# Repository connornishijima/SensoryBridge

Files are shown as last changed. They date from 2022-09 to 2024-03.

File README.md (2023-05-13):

https://github.com/connornishijima/SensoryBridge/assets/5051485/211737f4-0c69-49b0-99c4-2fa3d6a7a65e

# SENSORY BRIDGE is **DIFFERENT**

**This isn't the usual "sound-reactive LEDs" you've seen for years.**

**Sensory Bridge is built from the ground up as an open, powerful bridge between sight and sound.** With a show that's reactive to notation, vibrato and more, it produces very unique and pleasant-to-look-at light shows which synchronize to your music without any visible latency. (A built-in MEMS microphone constantly studies what it hears using a special-sauce Goertzel-based Discrete Fourier Transform, at 100 FPS!)

It has to be seen to be believed, *which the video demos below can help with:*

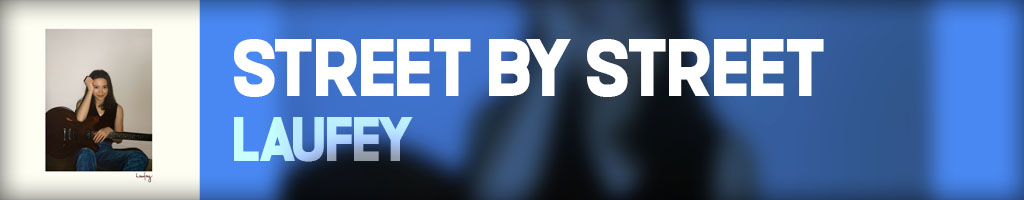
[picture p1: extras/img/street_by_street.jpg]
STREET BY STREET (https://www.youtube.com/watch?v=trJYa3U8nCU)

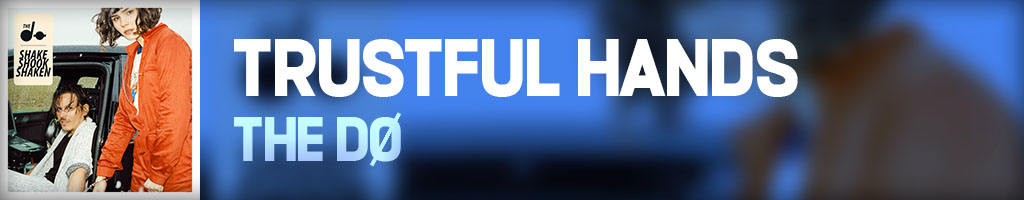
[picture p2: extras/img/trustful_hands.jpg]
TRUSTFUL_HANDS (https://www.youtube.com/watch?v=0EICjxSjveM)

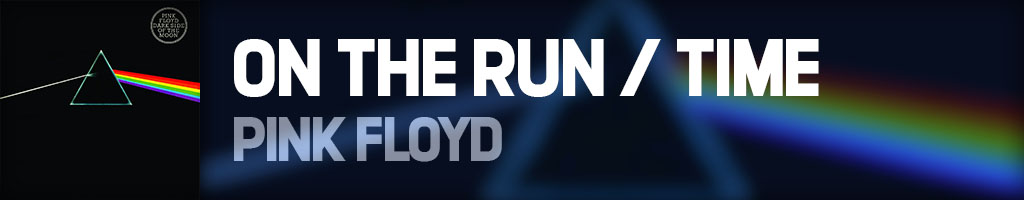
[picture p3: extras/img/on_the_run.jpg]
ON THE RUN (https://www.youtube.com/watch?v=RWJjWcHplGc)

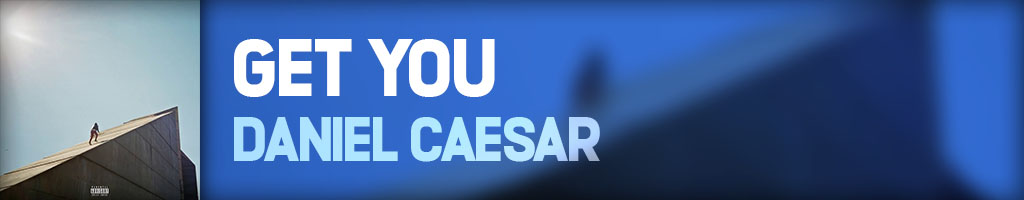
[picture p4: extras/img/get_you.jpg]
GET YOU (https://www.youtube.com/watch?v=lk1oRJr7TGo)

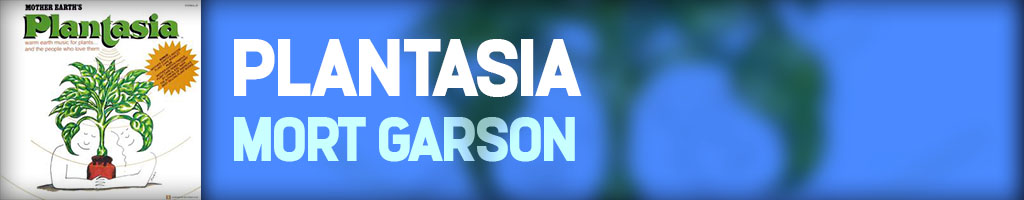
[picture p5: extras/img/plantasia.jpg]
PLANTASIA (https://www.youtube.com/watch?v=Hz8LxBKy5SI)

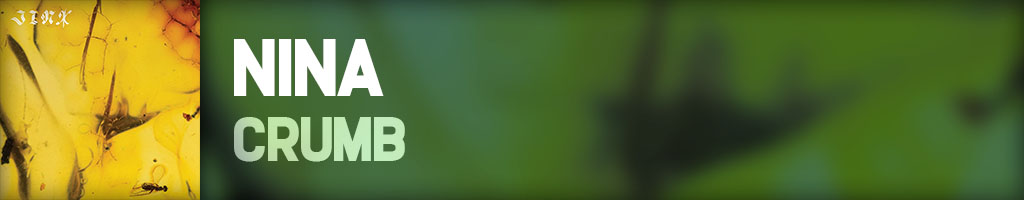
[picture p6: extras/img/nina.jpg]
NINA (https://www.youtube.com/watch?v=OXu3x7s3SVE)


# 

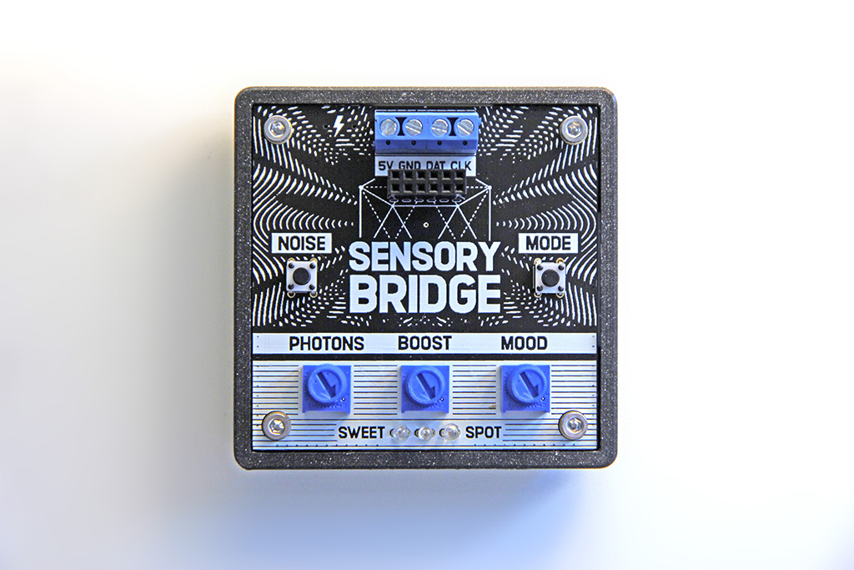
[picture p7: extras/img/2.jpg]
SENSORY BRIDGE IS SIMPLE


# SENSORY BRIDGE is **SIMPLE**

**Easy controls provide quick access to changing the brightness, color, and smoothing of the display!**

# **KNOBS**

## PHOTONS KNOB

Too bright? *Dim down the show* with the **PHOTONS** knob. The FastLED code in the firmware will use dithering to keep producing color nicely at lower brightness levels.

## CHROMA KNOB

Custom color or automated color based on the music's notation? Choose with the **CHROMA** knob, where turning it all the way to the top enables automated color changes.

## MOOD KNOB

This knob is special. **MOOD** controls *how quickly your LEDs will react to changes in pitch and volume!* A low "mood" will be very soft and gradual, only showing things like the underlying chord progression of a song, whereas a *high* "mood" will be extremely reactive, and can be a little too flashy for some people's liking. Luckily, you can blend the value to anywhere between those two extremes whenever you want to find what look you prefer!

# 

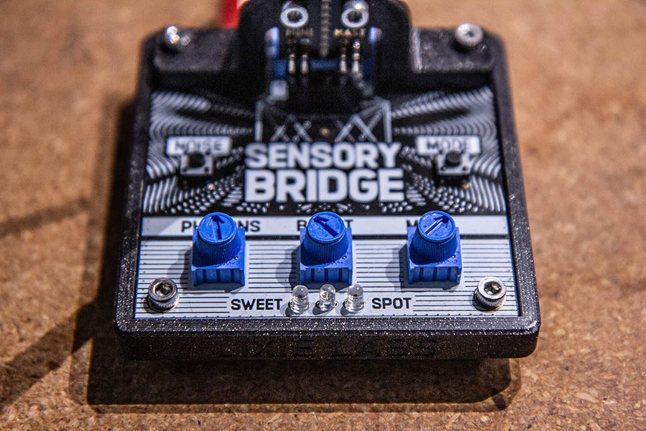
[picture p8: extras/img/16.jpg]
KNOBS


# **BUTTONS**

## NOISE BUTTON

Running the A/C? Is the washing machine suddenly on the spin cycle? Don't worry, just pause the music for a moment and press the **NOISE BUTTON** to run a 3-second calibration to *automagically* have noisy background ambience removed from your light show.

## MODE BUTTON

Sensory Bridge currently has 6 built-in light show modes that you can cycle through:

### "Spectrogram Mode"

This is the default show seen in the videos, based on Discrete Fourier Transform data. Each octave of notation shown on the display has a spectrum of colors for the individual notes, which are lit in sync with your music!

### "Chromagram Mode"

Similar to Spectrogram Mode, but all octaves of notes are rolled into one! Best with the **MOOD** knob at a low to medium setting.

### "Bloom Mode"

This mode differs from the others. The intensity of the audio is shown in the center of the LED strip, and is diffused outward in a non-linear fashion as time passes, leading to a 2001 "Stargate Sequence" effect!. Color is derived from the notes your music is playing.

### "Bloom Mode" (Faster)

Same as above, but double the speed for when you're partying hard!

### "VU Meter Mode"

It's a classic! A bouncing bar graph represents the current loudness of the music.

### "VU Meter Mode (Dot)"

Same as above, but represented with a dot instead of a bar, staying a constant brightness.

## ***MORE MODES WILL BE RELEASED IN FUTURE FIRMWARE UPDATES!***

# 

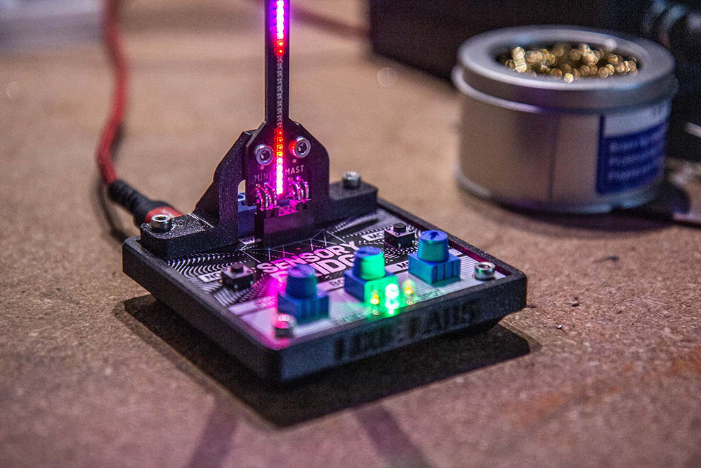
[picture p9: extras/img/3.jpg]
SWEET SPOT


# **SWEET SPOT**

At the front of the base unit are three LEDs, which indicate if your music is playing too quietly for the auto-ranger to account for, or if it's too loud! (Close to clipping!)

# 

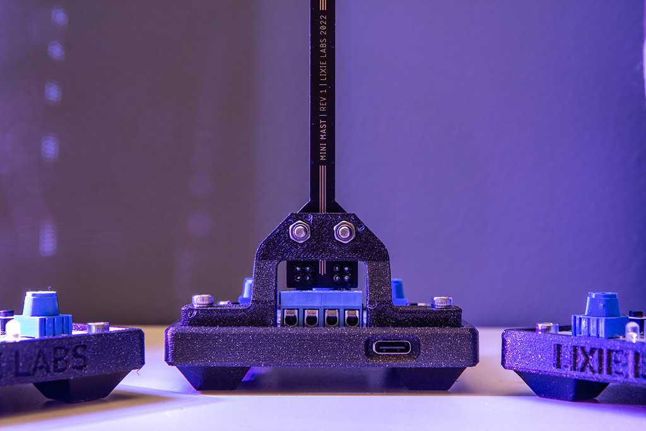
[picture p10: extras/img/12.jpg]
SENSORY BRIDGE IS FLEXIBLE


# SENSORY BRIDGE is **FLEXIBLE**

While compatible with any WS2812B or APA102/SK9822-based LED strip (just use the screw terminals at the back!) there's also the option of using the **"Mini Mast"**, a dense strip of 128 1.5mm RGB LEDs on a 260mm long PCB! It just plugs directly into the Sensory Bridge accessory port, making for a very portable solution!

# 

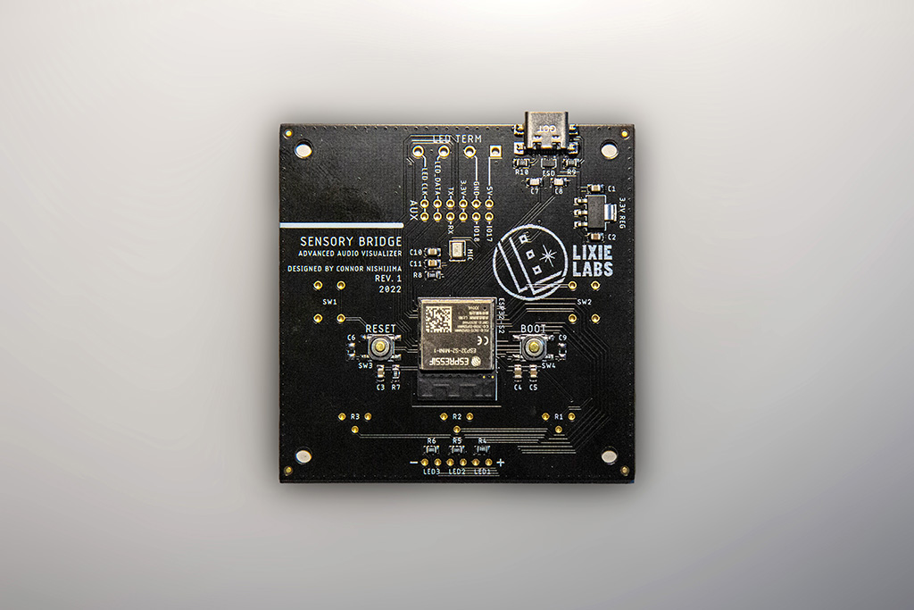
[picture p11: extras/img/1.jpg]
SENSORY BRIDGE IS OPEN


# SENSORY BRIDGE is **OPEN**

--------------------------------------------------------

### NOTE: This repo is used for active development.

For the latest stable release of the Sensory Bridge firmware, **[visit the Releases page](https://github.com/connornishijima/SensoryBridge/releases)**! (Cloning straight from this repo is much like a "nightly" build, and may be broken code!)

--------------------------------------------------------

Powered by an ESP32-S2, Sensory Bridge can be easily reprogrammed for any purpose you'd like! The firmware is [open source](https://github.com/connornishijima/SensoryBridge) under the [MIT License](https://github.com/connornishijima/SensoryBridge/blob/main/LICENSE), so modifying it for your own purposes is quick and easy with the Arduino IDE. You can even download the [board](https://github.com/connornishijima/SensoryBridge/tree/main/extras/OSHW/PCB) and [case STLs](https://github.com/connornishijima/SensoryBridge/tree/main/extras/OSHW/3D%20Printing) to build one yourself!

OSHW FACTS

# 

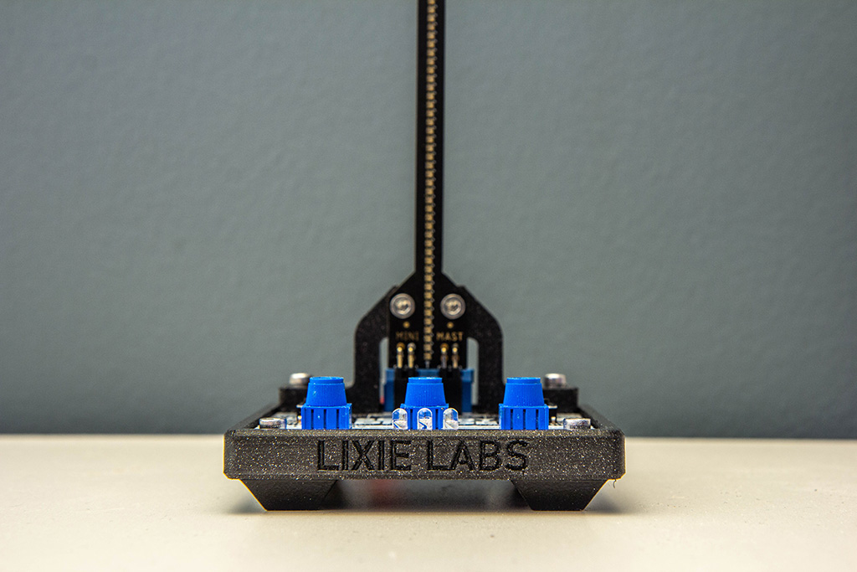
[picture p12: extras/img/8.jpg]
WHATS INCLUDED


# WHAT'S **INCLUDED:**

For $50, you'll receive a ***fully assembled Sensory Bridge***, with the latest firmware already installed. For $25 extra, you can have a **Mini Mast** (128 micro-LED PCB, seen above) sent as well, with an accompanying brace that provides rigidity. (It just plugs right into the accessory port on top of Sensory Bridge!)

# EXTRAS YOU **MIGHT NEED:**

## **PAY CLOSE ATTENTION TO THIS SECTION!**

To save on redundant materials you might already own, **your Sensory Bridge does *not* come with the following items:**

- **WS2812B LED Strip** - "144-LEDs per meter" variants are recommended, you can cut the 16 excess LEDs off of the end of the strip or reconfigure your device to interpolate to the 144-LED length at a slightly lower frame rate. ([AMAZON LINK](https://www.amazon.com/WS2812B-Individual-Addressable-144Pixels-Non-Waterproof/dp/B09PBHJG6G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))
- **USB-C Cable** ([AMAZON LINK](https://www.amazon.com/JSAUX-Charger-Braided-Compatible-Samsung/dp/B076FPGWNZ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))
- **5V, 2A USB Power Adapter** ([AMAZON LINK](https://www.amazon.com/Certified-Charger-FONKEN-Universal-Compatible/dp/B07DF782WQ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))
- **Wire Stripper** - If you'd like to use your Sensory Bridge with your own LED strip, you'll either need a wire stripper or strong teeth to get it hooked up neatly! These clamp-style strippers make that process a breeze, so please don't use your teeth: ([AMAZON LINK](https://www.amazon.com/Self-Adjusting-Stripper-Klein-Tools-11061/dp/B00CXKOEQ6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))

# 

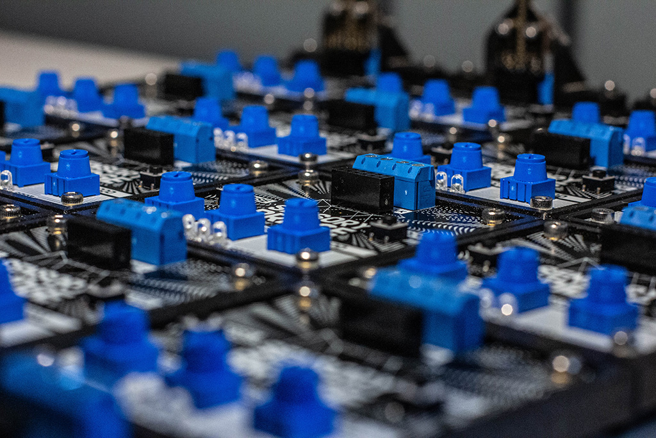
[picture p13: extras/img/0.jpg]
FUTURE PLANS


# FUTURE **PLANS**

Sensory Bridge is going to undergo some upgrades in the following months! You'll be able to easily [update to the latest firmware in minutes with this guide](DEAD LINK).

**Currently planned features are:**

## WiFi Features

Planned for Q1 2023 is a mobile / web app for iOS and Android that will allow users to remotely tweak their display from the couch! This will provide a way to adjust dozens of settings that otherwise couldn't be accessed through just two physical buttons.

## More Lightshow Modes

Currently in development is a system of determining and synchronizing to the BPM of the playing music. Combining this data with the GDFT could mean deducing time signatures, along with musical keys and chord progressions - just another avenue for providing an immersive show!

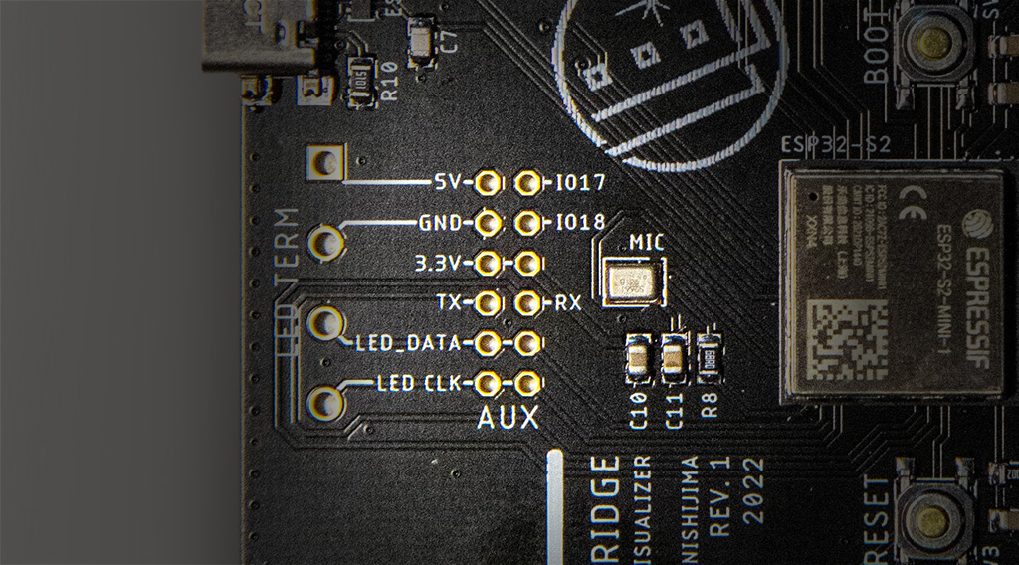
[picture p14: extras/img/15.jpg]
AUX PORT


## Support For Line-In Audio

The accessory port exposes GPIO 17/18 of the ESP32-S2, which are analog inputs. In the future, a PCB can be made to allow Sensory Bridge to use hardwired, passthrough audio via two 3.5mm jacks. This concept does not interfere with the Mini Mast, and the two accessories will be stackable with a modified brace.

GETTING STARTED GUIDE

# **GETTING STARTED**

The **[GETTING STARTED](https://sensorybridge.rocks/tutorial/) GUIDE** will walk you through the quick-and-easy setup process!

# **DISCLAIMER**

## **Those with [Photosensitive Epilepsy](https://en.wikipedia.org/wiki/Photosensitive_epilepsy) (PSE) should NOT purchase, operate, or otherwise view Sensory Bridge under any condition.**

## **The seller assumes no legal liability for injury caused to persons with PSE that have ignored this warning.**

# **SPONSORS**

- **[mlctrez](https://github.com/mlctrez)**
- **[zxcasd](https://github.com/zxcasd-zxcasd)**

# **CREDITS**

Developed by Connor Nishijima for Lixie Labs (2022)

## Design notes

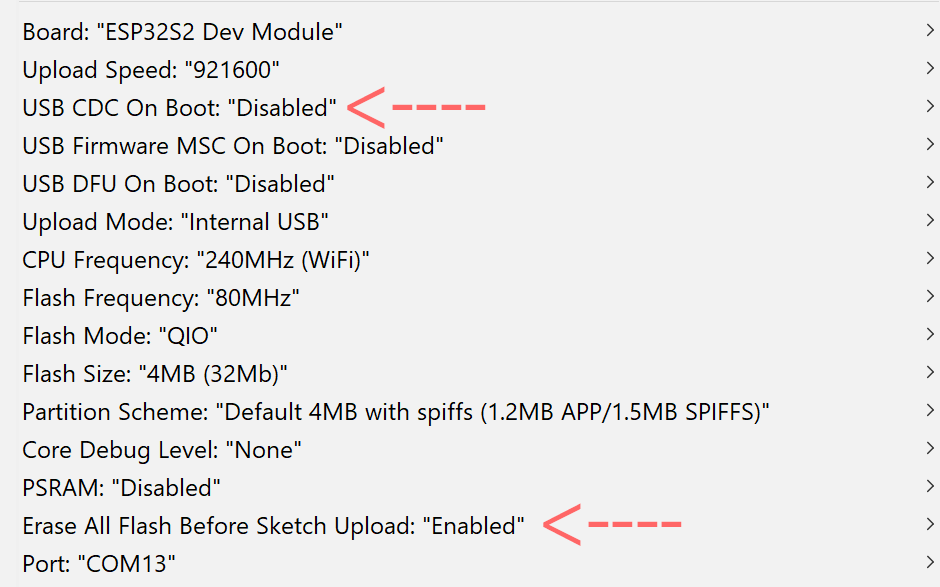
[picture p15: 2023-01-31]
extras/img/firmware_settings_300.png

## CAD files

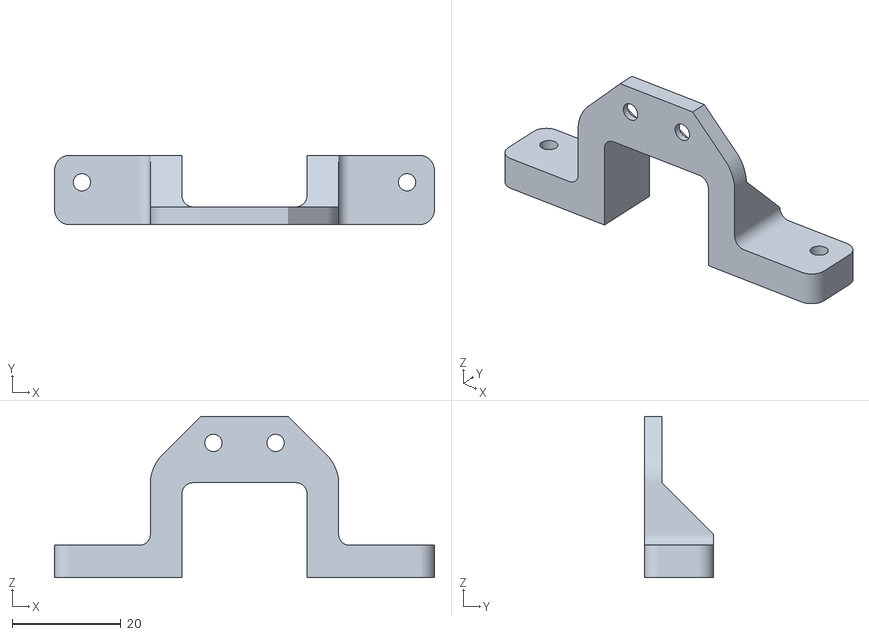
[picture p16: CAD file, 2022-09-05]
extras/OSHW/3D Printing/MINI_MAST_MOUNT.stl
70.0 x 12.8 x 29.7

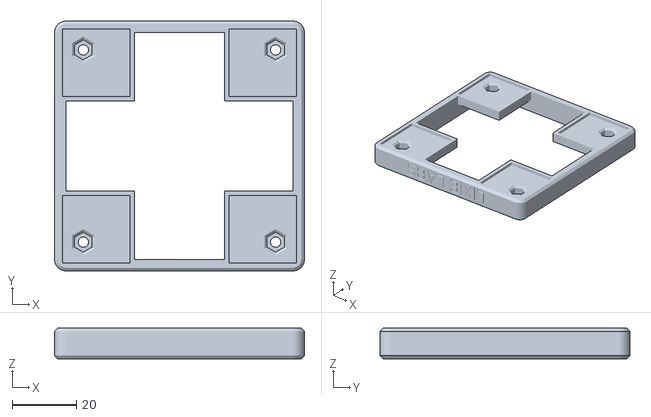
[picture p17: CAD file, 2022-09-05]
extras/OSHW/3D Printing/SENSORY_BRIDGE_BASE.stl
78.0 x 78.0 x 9.57

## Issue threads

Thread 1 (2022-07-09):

Add "shift" functionality to Mode Button

connornishijima, 2022-07-09:
**This is how to set hue, saturation, and hue-shift using the face knobs without affecting normal operation. This allows users to override the color generator and set their own display color semi-permanently, including white.**

- The Mode Button, when pressed, switches to the next available display mode.
- When held >= 0.5 seconds, the Mode Button should cause the audio engine to halt, and the display to be overridden with a fade-out.
- While still held, the display quickly fades back in to a gradient of BLACK-[COLOR]-BLACK, where [COLOR] is an RGB value whose hue and saturation are now to be decided by rotating the first two knobs.
- The third knob can be used to set the distance of "hue-shift" that occurs at changing brightness levels.
- Hue shift can be positive or negative, with the center of the knob being 0.0.
- In this example, only the hue (left knob) is changed.
- Once the Mode Button is released, the left-hand Sweet Spot LED will instantly begin flashing.
- On the display is two dots, a dim red one and a yellow one.
- The red dot's position on the light bar linearly represents the original rotation of the knob before entering this mode (it was once a brightness knob, which we don't want to affect)
- The yellow represents the currently measured rotation of the knob
- Dim green dots animate towards the red dot, from the yellow one.
- This is a readout of approximately how the user should rotate the knob to return it to its original, intended position.
- Automatically upon aligning the two dots within a threshold distance for more than X milliseconds, the Sensory Bridge returns to normal light show function, or refreshes the display to begin correcting a second or third knob until all of them are back in their approximate original positions. The Sweet Spot LEDs reflect which knob is currently being addressed.

Extra note: When a user sets a custom color, it persists with LittleFS through reboots and different mode selections until the mode button is held for >=0.5 and <=1.5 seconds to return it to the default color generation functions. When released before <= 1.5 seconds, the gradient normally shown during this mode is replaced with a rainbow version of itself that quickly cycles and fades out to alert the user that normal color functions have been restored, before fading back in to resume the light show.

connornishijima, 2022-11-17:
This idea was replaced in favor of the Chroma Knob in 2.0.0

Closed 2022-11-17.

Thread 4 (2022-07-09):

Factory Reset Function

connornishijima, 2022-07-09:
If both the Noise Cal and Mode buttons are held for =>3.0 seconds when plugging the unit in, all settings and flash contents should reset to factory state, including wiping the WiFi credentials.

connornishijima, 2022-11-17:
This is done via the "factory_reset" UART command as of 2.0.0!

Closed 2022-11-17.

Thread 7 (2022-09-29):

Alternate Voltage Regulator

Matlock42, 2022-09-29:
I noticed that the Tindie shop was out of stock, so I thought I'd look at building one myself. It seams that the designed voltage regulator (AP7361-33E-13) is out of stock, and there aren't any drop-in replacements. But there are similar 3.3v regs out there if you change the pins.

I didn't know if you'd be interested in supporting additional layouts due to chip shortage.

zenobik, 2022-11-21:
I used the TS2940CW33 regulator from Taiwan Semiconductors. This part is widely available: [octopart](https://octopart.com/search?q=TS2940CW33)

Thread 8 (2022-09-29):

Link to led strip broken

mlctrez, 2022-09-29:
Sometime between 9/26 and 9/28 the led strip product page on amazon was removed.

It is the first link in this section of the read me:
https://github.com/connornishijima/SensoryBridge#extras-you-might-need

mlctrez, 2022-10-01:
And it appears to be back.. Closing

Closed 2022-10-01.

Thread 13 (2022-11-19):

Miscellaneous clang warnings

mlctrez, 2022-11-19:
Some various warnings when porting this to esp-idf v5.0-rc1.

https://github.com/connornishijima/SensoryBridge/blob/43f3bf29ab7f229771669331037268d6427e105a/SENSORY_BRIDGE_FIRMWARE/serial_menu.h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
```text
'memset' used with constant zero length parameter; this could be due to transposed parameters
```
https://github.com/connornishijima/SensoryBridge/blob/43f3bf29ab7f229771669331037268d6427e105a/SENSORY_BRIDGE_FIRMWARE/fft_parser.h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
```text
warning: variable 'right_val' set but not used
which implies that left_val can also be removed
```

connornishijima, 2022-11-20:
Fixed in https://github.com/connornishijima/SensoryBridge/commit/26d3ebba74e1aefc431b3246cc72febecdb8e002!

RNG pin definition fixes are added now as well, thank you again for the bug hunt.

Closed 2022-11-20.

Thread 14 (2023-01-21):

Config struct member missing

mlctrez, 2023-01-21:
It looks like CONFIG.WAVEFORM_NOISE_FLOOR was removed in the last commit
https://github.com/connornishijima/SensoryBridge/commit/dc1723ddd79ccc060c36c365b3708477bb5a626a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

It's still referenced in
https://github.com/connornishijima/SensoryBridge/blob/dc1723ddd79ccc060c36c365b3708477bb5a626a/SENSORY_BRIDGE_FIRMWARE/serial_menu.h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

connornishijima, 2023-01-21:
Thank you Matt! *How embarrassing*, I'm not sure how I didn't catch that. As soon as 3.0.0 is done and out of beta, I've meaning to install CI workflows here like my Pixie Chroma repo. 😅

That `dump()` function in serial_menu.h is a bit bloated and hard to keep track of at this point, I wish there was a way for "Arduino C" to iterate over a struct and access a string value of each key's name in a `for` loop instead of the current brute force manual printing I'm doing, that could have avoided the issue. (Maybe ArduinoJSON lets me do that.)

Fixed in [182c288](https://github.com/connornishijima/SensoryBridge/commit/182c28834a68e85de550fb1a077a846eea175a5d), release re-issued as 3.0.0-beta4-bugfix. Enjoy the update!

mlctrez, 2023-01-22:
"given enough eyeballs, all bugs are shallow"

Thanks for releasing 3.0, enjoying it very much. It does seem that the beta4 has a much lower gain ( if this is the right term ) and the music must be playing quite a bit louder for it to work.  Is there a configuration setting that can be used to adjust the sensitivity?  I've not been tracking in the updates how the sensitivity works, maybe I'm missing something.

Closed 2023-01-21.

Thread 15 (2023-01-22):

Tweak settings for SK6812 / 5050rgbw LED strips

sammcj, 2023-01-22:
I have a SK6812 RGBW LED strip which works with SensoryBridge - but the white LEDs overpower the coloured.

I was wondering if it would be possible to add a setting that could adjust or even disable the white LEDs?

The strip is https://www.amazon.com.au/dp/B01MRSVRDD which is what is commonly sold in Australia now instead of WS2812B strips which seem to be being phased out here for some reason.

```
Model: SK6812 strip 5050rgbw chips
Input voltage: DC5V
Led Qty: 144pcs RGBW SMD 5050 per meter
Colour: RGBCW=RGB+White(6000-7000K)
Wave length(NM):R,650mcd ; G,520mcd ; B,460mcd
Power:43W/m
Length:1meters / 3.3ft
Signal:SK6812 IC(Similar with ws2812b) SK6812 chip built-in LED
View angle:120¡ã
Life span:more than 50000hrs
FPCB Width:12mm
Product Dimensions:L1000mmxW14mmxH4mm
Waterproof IP67.Covered with clear silicone weatherproof sheathing.
White PCB
```

Information on SK6812 - https://www.superlightingled.com/blog/sk6812-vs-ws2812b/

> "WS2812B is an upgraded version of WS2812, then SK6812 can be said to be an upgraded version of WS2812B."
> "All existing ws2812 libraries are compatible (often called "NeoPixel") and are the most used addressable LED strips in the Arduino community."

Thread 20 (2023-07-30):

init_leds() loop counter too small

bradanlane, 2023-07-30:
In most cases, the loop counter variable is a `uint16_t`. However, near the end of `init_leds()` there is the following lines of code which use an `uint8_t`. This becomes an infinite loop when there are more than 255 LEDs.

```C
for (uint8_t x = 0; x < CONFIG.LED_COUNT; x++) {
    leds_out[x] = CRGB(0, 0, 0);
  }
```

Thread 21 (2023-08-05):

LittleFS is not safe from interruptions

bradanlane, 2023-08-05:
If the LittleFS operations are interrupted- _for example by the LEDs processing thread_ - the file system will become corrupted.

One solution is to ...

1. set the `halt` flag and then wait some number of milliseconds to insure the LEDs processing thread has finished and looped around again
2. perform the necessary operations with LittleFS
3. restore the `halt` flag to allow LEDs processing to continue

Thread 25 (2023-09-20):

Ability to disable new UI system

andyshinn, 2023-09-20:
The new UI system is interesting but seems to trigger randomly for me when not touching the knobs. My guess sis maybe that throughout the day the knobs are moving slightly and triggering it. Either improving this detection or having an option to disable this behavior would be nice.

RWBRWB, 2024-02-29:
I noticed this also and wasn't sure what it was or if it was normal behavior.

Movent of the knobs or maybe slight noise may be causing it and making the detection threshold for triggering the display may solve this.

Juris3D, 2024-12-17:
Hello, I also self-assembled this super interesting (I am old a music-to-lights addict) construction, and, yes - periodically it goes kind-of like in adjust display mode. I might try brutally adding capacitors to those three analog (potis) inputs?

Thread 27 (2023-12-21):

Breaking I2S Changes in ESP32-Arduino 2.0.10+

connornishijima, 2023-12-21:
If you compile Sensory Bridge firmware from source on the 2.0.10 version (or higher) of the ESP32 Arduino core, the microphone will not work, returning the same value on every frame.

Matt Crawford helpfully discovered that the I2S "right only" and "left only" modes swapped places between the 2.0.9 and 2.0.10 versions of the ESP32 Arduino core. And you can't even fucking install 2.0.9 anymore in the IDE, which doesn't help anyone.

Sensory Bridge works great from the pre-compiled .BIN in releases, but will fail unless the FMT_RIGHT_ONLY in i2s_audio.h is changed to FMT_LEFT_ONLY in the i2s_config struct. Once that change is made everything works again.

Why this changed, I don't know!

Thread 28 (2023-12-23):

Compilation error: redefinition of 'char notes_chromatic [12]'

Mnikley, 2023-12-23:
Tried to update the firmware from i think 2.X to 4.0.0, but after hitting CTRL+U i get the following exception:

```
exit status 1

Compilation error: redefinition of 'char notes_chromatic [12]'
```

- Arduino IDE 2.2.1
- newest version of FastLED and FixedPoints
- board settings as proposed in https://github.com/connornishijima/SensoryBridge/releases/tag/4.0.0
- connected board: ESP32S2 Dev Module
-

part of the stacktrace:
```
c:\Users\usrusr\Documents\Arduino\libraries\FastLED\src/fastspi_bitbang.h:142:144: error: no matching function for call to 'delaycycles<4294967294>()'
  142 |         #define CLOCK_HI_DELAY do { delaycycles<MIN_DELAY>(); delaycycles<((SPI_SPEED > 10) ? (((SPI_SPEED-6) / 2) - MIN_DELAY) : (SPI_SPEED))>(); } while(0);
      |                                                               ~~~~~~~~~~~~~~~~~~~~~~~~~~~~~~~~~~~~~~~~~~~~~~~~~~~~~~~~~~~~~~~~~~~~~~~~~~~~~~~~~^~
c:\Users\usrusr\Documents\Arduino\libraries\FastLED\src/fastspi_bitbang.h:168:55: note: in expansion of macro 'CLOCK_HI_DELAY'
  168 |                         FastPin<CLOCK_PIN>::toggle(); CLOCK_HI_DELAY;
      |                                                       ^~~~~~~~~~~~~~
c:\Users\usrusr\Documents\Arduino\libraries\FastLED\src/fastled_delay.h:129:65: note: candidate: 'template<int CYCLES> void delaycycles()'
  129 | template<int CYCLES> __attribute__((always_inline)) inline void delaycycles() {
      |                                                                 ^~~~~~~~~~~
c:\Users\usrusr\Documents\Arduino\libraries\FastLED\src/fastled_delay.h:129:65: note:   template argument deduction/substitution failed:
c:\Users\usrusr\Documents\Arduino\libraries\FastLED\src/fastspi_bitbang.h:142:144: error: narrowing conversion of '4294967294' from 'long unsigned int' to 'int' [-Wnarrowing]
  142 |         #define CLOCK_HI_DELAY do { delaycycles<MIN_DELAY>(); delaycycles<((SPI_SPEED > 10) ? (((SPI_SPEED-6) / 2) - MIN_DELAY) : (SPI_SPEED))>(); } while(0);
      |                                                               ~~~~~~~~~~~~~~~~~~~~~~~~~~~~~~~~~~~~~~~~~~~~~~~~~~~~~~~~~~~~~~~~~~~~~~~~~~~~~~~~~^~
c:\Users\usrusr\Documents\Arduino\libraries\FastLED\src/fastspi_bitbang.h:168:55: note: in expansion of macro 'CLOCK_HI_DELAY'
  168 |                         FastPin<CLOCK_PIN>::toggle(); CLOCK_HI_DELAY;
      |                                                       ^~~~~~~~~~~~~~
```

connornishijima, 2024-01-13:
I think I just figured this one out:

Are you on the pre-release ESP32 board definitions inside Arduino? (v3.0.0-alpha?)

Sensory Bridge Firmware was compiled using the 2.0.9 ESP32 board definitions. If you don't see 2.0.9 in your Boards Manager, you need to switch from the dev version to the stable version:

Dev versions:
https://espressif.github.io/arduino-esp32/package_esp32_dev_index.json

Stable versions:
https://espressif.github.io/arduino-esp32/package_esp32_index.json

There are breaking changes in 2.0.10 to how the I2S mic is accessed, (left and right channel data swapped positions in 2.0.10 for some reason) and ESP32 3.0.0+ is entirely incompatible because I need to port things to the entirely new I2S system in that version.

This means that any existing version of Sensory Bridge firmware as of writing this must be compiled using exactly the 2.0.9 ESP32 version in Boards Manager.

Please let me know if this fixed it!

Mnikley, 2024-01-13:
yep, you are right, i was on v3.0.0-a because of the dev version. Switched the additional boards manager url to the stable version ([tutorial here](https://docs.espressif.com/projects/arduino-esp32/en/latest/installing.html)). However, after compiling/verification and the uploading this is my output:
```
In file included from c:\Users\xx\Documents\Arduino\libraries\FastLED\src/FastLED.h:75,
                 from C:\Users\xx\Desktop\SensoryBridge-4.0.0\SENSORY_BRIDGE_FIRMWARE\SENSORY_BRIDGE_FIRMWARE.ino:74:
c:\Users\xx\Documents\Arduino\libraries\FastLED\src/fastspi.h:157:23: note: #pragma message: No hardware SPI pins defined.  All SPI access will default to bitbanged output
 #      pragma message "No hardware SPI pins defined.  All SPI access will default to bitbanged output"
                       ^~~~~~~~~~~~~~~~~~~~~~~~~~~~~~~~~~~~~~~~~~~~~~~~~~~~~~~~~~~~~~~~~~~~~~~~~~~~~~~~
In file included from C:\Users\xx\Desktop\SensoryBridge-4.0.0\SENSORY_BRIDGE_FIRMWARE\SENSORY_BRIDGE_FIRMWARE.ino:91:
C:\Users\xx\Desktop\SensoryBridge-4.0.0\SENSORY_BRIDGE_FIRMWARE\i2s_audio.h:12:48: warning: 'I2S_COMM_FORMAT_I2S' is deprecated [-Wdeprecated-declarations]
   .communication_format = (i2s_comm_format_t) (I2S_COMM_FORMAT_I2S | I2S_COMM_FORMAT_I2S_MSB),
                                                ^~~~~~~~~~~~~~~~~~~
In file included from C:\Users\xx\AppData\Local\Arduino15\packages\esp32\hardware\esp32\2.0.9/tools/sdk/esp32s2/include/driver/include/driver/i2s.h:16,
                 from C:\Users\xx\Desktop\SensoryBridge-4.0.0\SENSORY_BRIDGE_FIRMWARE\i2s_audio.h:5,
                 from C:\Users\xx\Desktop\SensoryBridge-4.0.0\SENSORY_BRIDGE_FIRMWARE\SENSORY_BRIDGE_FIRMWARE.ino:91:
C:\Users\xx\AppData\Local\Arduino15\packages\esp32\hardware\esp32\2.0.9/tools/sdk/esp32s2/include/hal/include/hal/i2s_types.h:87:5: note: declared here
     I2S_COMM_FORMAT_I2S       __attribute__((deprecated)) = 0x01, /*!< I2S communication format I2S, correspond to `I2S_COMM_FORMAT_STAND_I2S`*/
     ^~~~~~~~~~~~~~~~~~~
In file included from C:\Users\xx\Desktop\SensoryBridge-4.0.0\SENSORY_BRIDGE_FIRMWARE\SENSORY_BRIDGE_FIRMWARE.ino:91:
C:\Users\xx\Desktop\SensoryBridge-4.0.0\SENSORY_BRIDGE_FIRMWARE\i2s_audio.h:12:70: warning: 'I2S_COMM_FORMAT_I2S_MSB' is deprecated [-Wdeprecated-declarations]
   .communication_format = (i2s_comm_format_t) (I2S_COMM_FORMAT_I2S | I2S_COMM_FORMAT_I2S_MSB),
                                                                      ^~~~~~~~~~~~~~~~~~~~~~~
In file included from C:\Users\xx\AppData\Local\Arduino15\packages\esp32\hardware\esp32\2.0.9/tools/sdk/esp32s2/include/driver/include/driver/i2s.h:16,
                 from C:\Users\xx\Desktop\SensoryBridge-4.0.0\SENSORY_BRIDGE_FIRMWARE\i2s_audio.h:5,
                 from C:\Users\xx\Desktop\SensoryBridge-4.0.0\SENSORY_BRIDGE_FIRMWARE\SENSORY_BRIDGE_FIRMWARE.ino:91:
C:\Users\xx\AppData\Local\Arduino15\packages\esp32\hardware\esp32\2.0.9/tools/sdk/esp32s2/include/hal/include/hal/i2s_types.h:88:5: note: declared here
     I2S_COMM_FORMAT_I2S_MSB   __attribute__((deprecated)) = 0x01, /*!< I2S format MSB, (I2S_COMM_FORMAT_I2S |I2S_COMM_FORMAT_I2S_MSB) correspond to `I2S_COMM_FORMAT_STAND_I2S`*/
     ^~~~~~~~~~~~~~~~~~~~~~~
In file included from C:\Users\xx\Desktop\SensoryBridge-4.0.0\SENSORY_BRIDGE_FIRMWARE\SENSORY_BRIDGE_FIRMWARE.ino:98:
C:\Users\xx\Desktop\SensoryBridge-4.0.0\SENSORY_BRIDGE_FIRMWARE\system.h: In function 'void generate_a_weights()':
C:\Users\xx\Desktop\SensoryBridge-4.0.0\SENSORY_BRIDGE_FIRMWARE\system.h:162:38: warning: ISO C++ forbids converting a string constant to 'char*' [-Wwrite-strings]
   start_timing("GENERATING A-WEIGHTS");
                                      ^
C:\Users\xx\Desktop\SensoryBridge-4.0.0\SENSORY_BRIDGE_FIRMWARE\system.h: In function 'void generate_window_lookup()':
C:\Users\xx\Desktop\SensoryBridge-4.0.0\SENSORY_BRIDGE_FIRMWARE\system.h:198:53: warning: ISO C++ forbids converting a string constant to 'char*' [-Wwrite-strings]
   start_timing("GENERATING HANN WINDOW LOOKUP TABLE");
                                                     ^
C:\Users\xx\Desktop\SensoryBridge-4.0.0\SENSORY_BRIDGE_FIRMWARE\system.h: In function 'void init_system()':
C:\Users\xx\Desktop\SensoryBridge-4.0.0\SENSORY_BRIDGE_FIRMWARE\system.h:291:26: warning: ISO C++ forbids converting a string constant to 'char*' [-Wwrite-strings]
   set_mode_name(0, "GDFT");
                          ^
C:\Users\xx\Desktop\SensoryBridge-4.0.0\SENSORY_BRIDGE_FIRMWARE\system.h:292:32: warning: ISO C++ forbids converting a string constant to 'char*' [-Wwrite-strings]
   set_mode_name(1, "CHROMAGRAM");
                                ^
C:\Users\xx\Desktop\SensoryBridge-4.0.0\SENSORY_BRIDGE_FIRMWARE\system.h:293:27: warning: ISO C++ forbids converting a string constant to 'char*' [-Wwrite-strings]
   set_mode_name(2, "BLOOM");
                           ^
C:\Users\xx\Desktop\SensoryBridge-4.0.0\SENSORY_BRIDGE_FIRMWARE\system.h:294:34: warning: ISO C++ forbids converting a string constant to 'char*' [-Wwrite-strings]
   set_mode_name(3, "BLOOM (FAST)");
                                  ^
C:\Users\xx\Desktop\SensoryBridge-4.0.0\SENSORY_BRIDGE_FIRMWARE\system.h:295:24: warning: ISO C++ forbids converting a string constant to 'char*' [-Wwrite-strings]
   set_mode_name(4, "VU");
                        ^
C:\Users\xx\Desktop\SensoryBridge-4.0.0\SENSORY_BRIDGE_FIRMWARE\system.h:296:30: warning: ISO C++ forbids converting a string constant to 'char*' [-Wwrite-strings]
   set_mode_name(5, "VU (DOT)");
                              ^
Sketch uses 825738 bytes (62%) of program storage space. Maximum is 1310720 bytes.
Global variables use 102988 bytes (31%) of dynamic memory, leaving 224692 bytes for local variables. Maximum is 327680 bytes.
esptool.py v4.5.1
Serial port COM5
Connecting...
Chip is ESP32-S2FH4 (revision v0.0)
Features: WiFi, Embedded Flash 4MB, No Embedded PSRAM, ADC and temperature sensor calibration in BLK2 of efuse V1
Crystal is 40MHz
MAC: 84:f7:03:fc:f9:9a
Uploading stub...
Running stub...
Stub running...
Changing baud rate to 921600
Changed.
Configuring flash size...
Erasing flash (this may take a while)...
Chip erase completed successfully in 17.5s
Compressed 14656 bytes to 10171...
Writing at 0x00001000... (20 %)
Writing at 0x00001c5d... (40 %)
Writing at 0x000027ad... (60 %)
Writing at 0x000032ca... (80 %)
Writing at 0x00003c93... (100 %)
Wrote 14656 bytes (10171 compressed) at 0x00001000 in 0.3 seconds (effective 436.3 kbit/s)...
Hash of data verified.
Compressed 3072 bytes to 146...
Writing at 0x00008000... (100 %)
Wrote 3072 bytes (146 compressed) at 0x00008000 in 0.1 seconds (effective 357.3 kbit/s)...
Hash of data verified.
Compressed 8192 bytes to 47...
Writing at 0x0000e000... (100 %)
Wrote 8192 bytes (47 compressed) at 0x0000e000 in 0.1 seconds (effective 486.5 kbit/s)...
Hash of data verified.
Compressed 826096 bytes to 546381...
Writing at 0x00010000... (0 %)
...
Writing at 0x000d90e3... (100 %)
Wrote 826096 bytes (546381 compressed) at 0x00010000 in 10.0 seconds (effective 657.8 kbit/s)...
Hash of data verified.

Leaving...
Hard resetting via RTS pin...
```

After which the LEDs are all white (still react to sounds though, but the pattern seems a little off). So I thought the update worked, but unfortunately the next step to update with the USB Update process doesn't work since i cannot establish a connection (Edge as browser) - console output:
```
GET https://unpkg.com/p5-webserial@0.1.1/build/p5.webserial.js net::ERR_ADDRESS_INVALID
settings.sensorybridge.rocks/:500

        GET https://unpkg.com/@popperjs/core@2.11.5/dist/umd/popper.min.js net::ERR_ADDRESS_INVALID
settings.sensorybridge.rocks/:501

        GET https://unpkg.com/tippy.js@6.3.7/dist/tippy-bundle.umd.min.js net::ERR_ADDRESS_INVALID
auto_serial_p5.js?version=4:2  Uncaught TypeError: p5.WebSerial is not a constructor
    at auto_serial_p5.js?version=4:2:16
(anonymous) @ auto_serial_p5.js?version=4:2
(index):488 REMOTE VERSION IS 4.0.0
auto_serial_p5.js?version=4:603  Uncaught (in promise) ReferenceError: Cannot access 'serial' before initialization
    at setup (auto_serial_p5.js?version=4:603:2)
    at v._setup (p5.min.js:2:461622)
    at v._start (p5.min.js:2:460389)
    at new v (p5.min.js:2:464548)
    at p5.min.js:2:451299
```
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

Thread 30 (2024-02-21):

Freezing with MicroDose on 4.1.0

andyshinn, 2024-02-21:
The MicroDose looks pretty good. But after a couple hours the lighting on the Sensory Bridge freezes. Other functions still seem to be working (the sweet spot LEDs are moving and I can connect to the device over USB). When I change back to the mast and set the LED settings for the mast it doesn't freeze. Maybe a bug somewhere specific to the output for MicroDose?

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

RWBRWB, 2024-02-29:
Same issue here with the Microdose.

Exactly the same freezing of the LED's while the other functions look to be working and USB output to the chrome page still shows updated FPS numbers.

The main mast works perfectly.

Seems to bet an error with the dual 128 pixel output code.

Looks great otherwise and looking forward to getting this bug found and fixed.

RWBRWB, 2024-02-29:
> The MicroDose looks pretty good. But after a couple hours the lighting on the Sensory Bridge freezes. Other functions still seem to be working (the sweet spot LEDs are moving and I can connect to the device over USB). When I change back to the mast and set the LED settings for the mast it doesn't freeze. Maybe a bug somewhere specific to the output for MicroDose?
>
> ![IMG_1358](https://private-user-images.githubusercontent.com/315485/306699841-ce4f7768-b0d6-4efb-8056-4079fe75b7e9.jpeg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)

Try setting the LED count to 130 Pixels and see if it still crashes on you. So far it's running longer than usual when using 130 pixel count with the Microdose.

126 pixel count seemed not crash quick from my quick test also but it does leave 2 leds not working when you do that which is better than crashing but with the 130 pixel setting you get all LED's and so far no crashing.

Need longer term testing to see if it fixes the issue until the bug is fixed.

RWBRWB, 2024-02-29:
> The MicroDose looks pretty good. But after a couple hours the lighting on the Sensory Bridge freezes. Other functions still seem to be working (the sweet spot LEDs are moving and I can connect to the device over USB). When I change back to the mast and set the LED settings for the mast it doesn't freeze. Maybe a bug somewhere specific to the output for MicroDose?
>
> ![IMG_1358](https://private-user-images.githubusercontent.com/315485/306699841-ce4f7768-b0d6-4efb-8056-4079fe75b7e9.jpeg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)

Until it's fixed you can solder the center to 1 pads on the back of the Microdose PCB and then just set the mast to be the regular 128 LED mast and it will work without crashing and to me looks exactly the same even though the refresh rate is lower I guess since your not driving 64 LED's separately anymore.

You can change it back to dual data line by removing the solder jumper once the code is fixed.

This will let you enjoy the Microdose without needing to reset it everyday.

I love these things LOL

connornishijima, 2024-02-29:
I'm updating to let you guys know that I've started to investigate the MicroDose issue today, hang tight for a fix! It must be something I changed in 4.1.0.

connornishijima, 2024-03-22:
4.1.1 is out now, which has fixed the LED thread lockup issues!

https://github.com/connornishijima/SensoryBridge/releases/tag/4.1.1

andyshinn, 2024-03-25:
It is working for longer periods now. But it seems to lock up similarly overnight. I notice the next morning the same behavior where the LEDs do not respond (everything stays off) but I do see the sweet spot LEDs responding to sound.

jhermans73, 2024-04-12:
Same problem here - sometimes a few hours, occasionally a few days, before lockup.  I guess it's better than the 30 seconds to 10 minutes I was experiencing with 4.1.0.

Closed 2024-03-22.

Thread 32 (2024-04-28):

"403 Forbidden Access to this resource on the server is denied" after update

jasonfish, 2024-04-28:
I updated today to 4.1.1  from either 3.2.0 or 4.0.0, I can't recall. The update seemed to work, the file copies and the device restarts. I've held both buttons while plugging it back in, and I can calibrate the noise floor with the Noise button (yellow and green lights respond properly to noise) so the device is "awake." But I can no longer get to the settings page. Chrome, Firefox and Safari all show the error in the title. Downgrading to older firmwares does not fix it. I've tried 3 different USB ports and 3 different cables, no change.

Without the ability to set up my specific settings, the device isn't usable.

Help?

FalconFour, 2025-09-17:
By the power of Claude Code... here is a second pass. And I dare say it's a pretty-dang-competent second pass...

[Archive.zip](https://github.com/user-attachments/files/22376638/Archive.zip)

Extract it, then run `python3 -m http.server 8000` inside the folder. Then browse to http://localhost:8000/ to get the control interface and connect to it.

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

I've tried many of the controls and they all seem to work. Claude spotted a whole slew of issues with the previous version, reworked the entire engine, rewrote the entire CSS, and patched up the last remaining nice-to-haves, in about 15 minutes.

Now I've got control of my Sensory Bridge again, ready for a show this weekend with the "Mega Mast" I created for stage show :)

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

Rock on.

Juris3D, 2025-09-17:
I am following this (since a big fan of music-to-lights for decades), just want to say Thank You for your work, FalconFour, and, I agree that Claude is quite capable and usable for coding tasks (if you know how to direct it :) )

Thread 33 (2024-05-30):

(Still) Freezing with MicroDose on 4.1.1

jhermans73, 2024-05-30:
Bar LEDs are still locking up on 4.1.1 - there seems to be a slightly longer runtime than 4.1.0, but it's still an issue unfortunately.

As before, the Sensory Bridge still responds via USB, sweet spot LEDs are active, and a soft reboot works to bring activity back for a bit.

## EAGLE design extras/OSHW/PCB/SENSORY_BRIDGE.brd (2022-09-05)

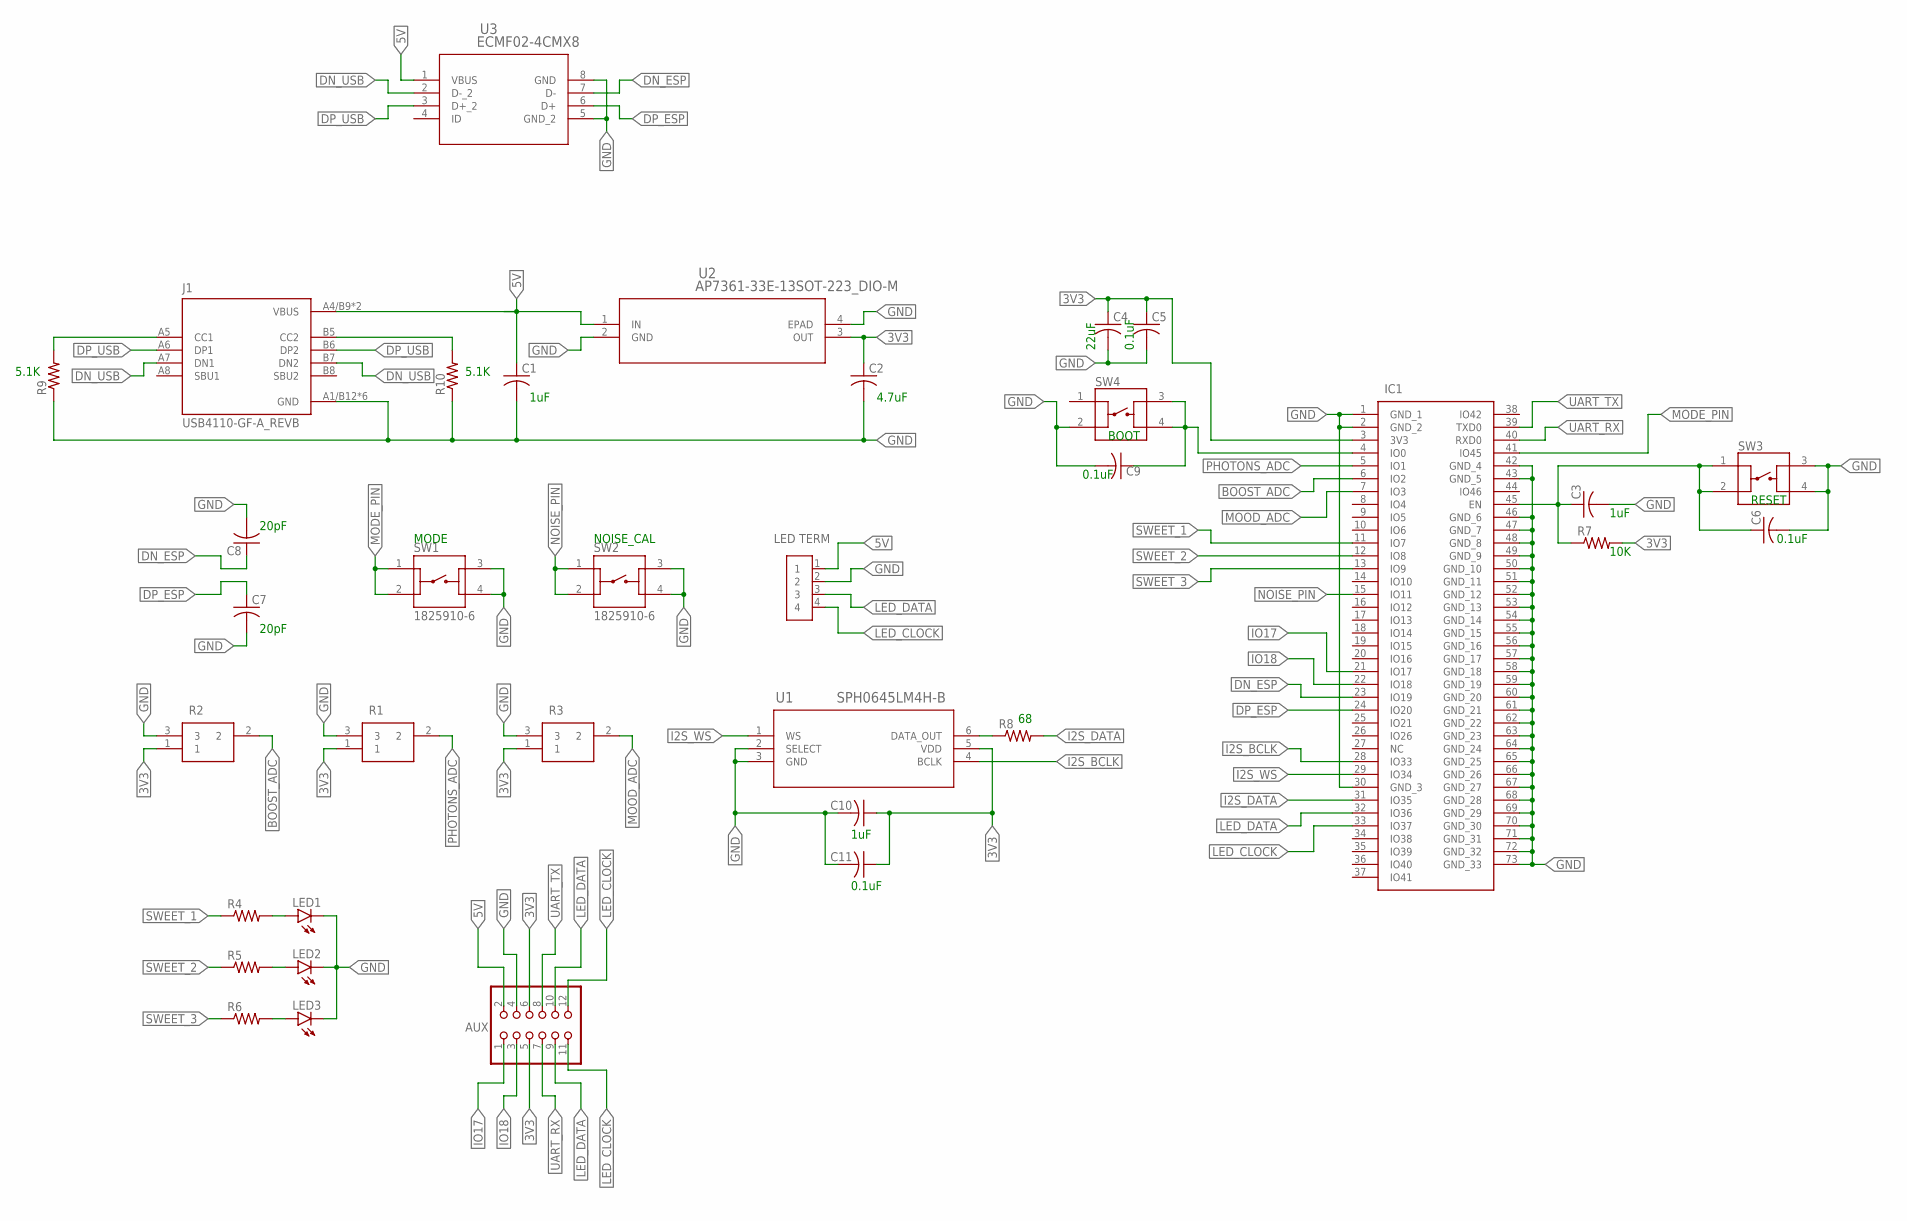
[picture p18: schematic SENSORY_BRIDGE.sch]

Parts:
C1, C2, C3, C4, C5, C6, C7, C8, C9, C10, C11: C-USC0805K; C0805K
IC1: ESP32-S2-MINI-1-N4R2; ESP32S2MINI1N4R2
J1: USB4110-GF-A_REVB; GCT_USB4110-GF-A_REVB
J2: 796949-4; TE_796949-4
JP1: PINHD-2X6; 2X06
LED1, LED2, LED3: LED3MM
R1, R2, R3: 3386P-1-103LF; 3386P_1
R4, R5, R6, R7, R8, R9, R10: R-US_R0805; R0805
SW1, SW2: 1825910-6; SW_1825910-6-4
SW3, SW4: PTS525SM15SMTR2LFS; SW_PTS525SM15SMTR2LFS
U1: SPH0645LM4H-B; SPH0645LM4H-B_KNO
U2: AP7361-33E-13SOT-223_DIO-M; SOT-223_DIO-M
U3: ECMF02-4CMX8; MICRO_QFN-8L_STM

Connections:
3V3: C2.1, C4.1, C5.1, C10.1, C11.1, IC1.3 (3V3), JP1.5, JP1.6, R1.1, R2.1, R3.1, R7.2, U1.5 (VDD), U2.3 (OUT)
5V: C1.1, J1.A4/B9 (VBUS), J1.B4/A9 (VBUS), J2.1, JP1.2, U2.1 (IN), U3.1 (VBUS)
BOOST_ADC: IC1.6 (IO2), R2.2
BOOT_LINE: C9.1, IC1.4 (IO0), SW4.3, SW4.4
CC1: J1.A5 (CC1), R9.2
CC2: J1.B5 (CC2), R10.2
DN_ESP: C8.1, IC1.23 (IO19), U3.7 (D-)
DN_USB: J1.A7 (DN1), J1.B7 (DN2), U3.2 (D-_2)
DP_ESP: C7.1, IC1.24 (IO20), U3.6 (D+)
DP_USB: J1.A6 (DP1), J1.B6 (DP2), U3.3 (D+_2)
GND: C1.2, C2.2, C3.2, C4.2, C5.2, C6.2, C7.2, C8.2, C9.2, C10.2, C11.2, IC1.1 (GND_1), IC1.2 (GND_2), IC1.30 (GND_3), IC1.42 (GND_4), IC1.43 (GND_5), IC1.46 (GND_6), IC1.47 (GND_7), IC1.48 (GND_8), IC1.49 (GND_9), IC1.50 (GND_10), IC1.51 (GND_11), IC1.52 (GND_12), IC1.53 (GND_13), IC1.54 (GND_14), IC1.55 (GND_15), IC1.56 (GND_16), IC1.57 (GND_17), IC1.58 (GND_18), IC1.59 (GND_19), IC1.60 (GND_20), IC1.61 (GND_21), IC1.62 (GND_22), IC1.63 (GND_23), IC1.64 (GND_24), IC1.65 (GND_25), IC1.66 (GND_26), IC1.67 (GND_27), IC1.68 (GND_28), IC1.69 (GND_29), IC1.70 (GND_30), IC1.71 (GND_31), IC1.72 (GND_32), IC1.73 (GND_33), J1.A1/B12 (GND), J1.B1/A12 (GND), J1.S1 (GND), J1.S2 (GND), J1.S3 (GND), J1.S4 (GND), J2.2, JP1.4, LED1.K (C), LED2.K (C), LED3.K (C), R1.3, R2.3, R3.3, R9.1, R10.1, SW1.3, SW1.4, SW2.3, SW2.4, SW3.3, SW3.4, SW4.2, U1.2 (SELECT), U1.3 (GND), U2.2 (GND), U2.4 (EPAD), U3.5 (GND_2), U3.8 (GND)
I2S_BCLK: IC1.28 (IO33), U1.4 (BCLK)
I2S_DATA: IC1.31 (IO35), R8.2
I2S_WS: IC1.29 (IO34), U1.1 (WS)
IO17: IC1.21 (IO17), JP1.1
IO18: IC1.22 (IO18), JP1.3
LED_CLOCK: IC1.33 (IO37), J2.4, JP1.11, JP1.12
LED_DATA: IC1.32 (IO36), J2.3, JP1.9, JP1.10
MODE_PIN: IC1.41 (IO45), SW1.1, SW1.2
MOOD_ADC: IC1.7 (IO3), R3.2
unnamed: R8.1, U1.6 (DATA_OUT)
unnamed: LED1.A, R4.2
unnamed: LED2.A, R5.2
unnamed: LED3.A, R6.2
NOISE_PIN: IC1.15 (IO11), SW2.1, SW2.2
PHOTONS_ADC: IC1.5 (IO1), R1.2
RESET_LINE: C3.1, C6.1, IC1.45 (EN), R7.1, SW3.1, SW3.2
SWEET_1: IC1.11 (IO7), R4.1
SWEET_2: IC1.12 (IO8), R5.1
SWEET_3: IC1.13 (IO9), R6.1
UART_RX: IC1.40 (RXD0), JP1.7
UART_TX: IC1.39 (TXD0), JP1.8

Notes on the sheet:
1uF
4.7uF
10K
22uF
0.1uF
BOOT
RESET
20pF
NOISE_CAL
MODE
5.1K
LED TERM
AUX

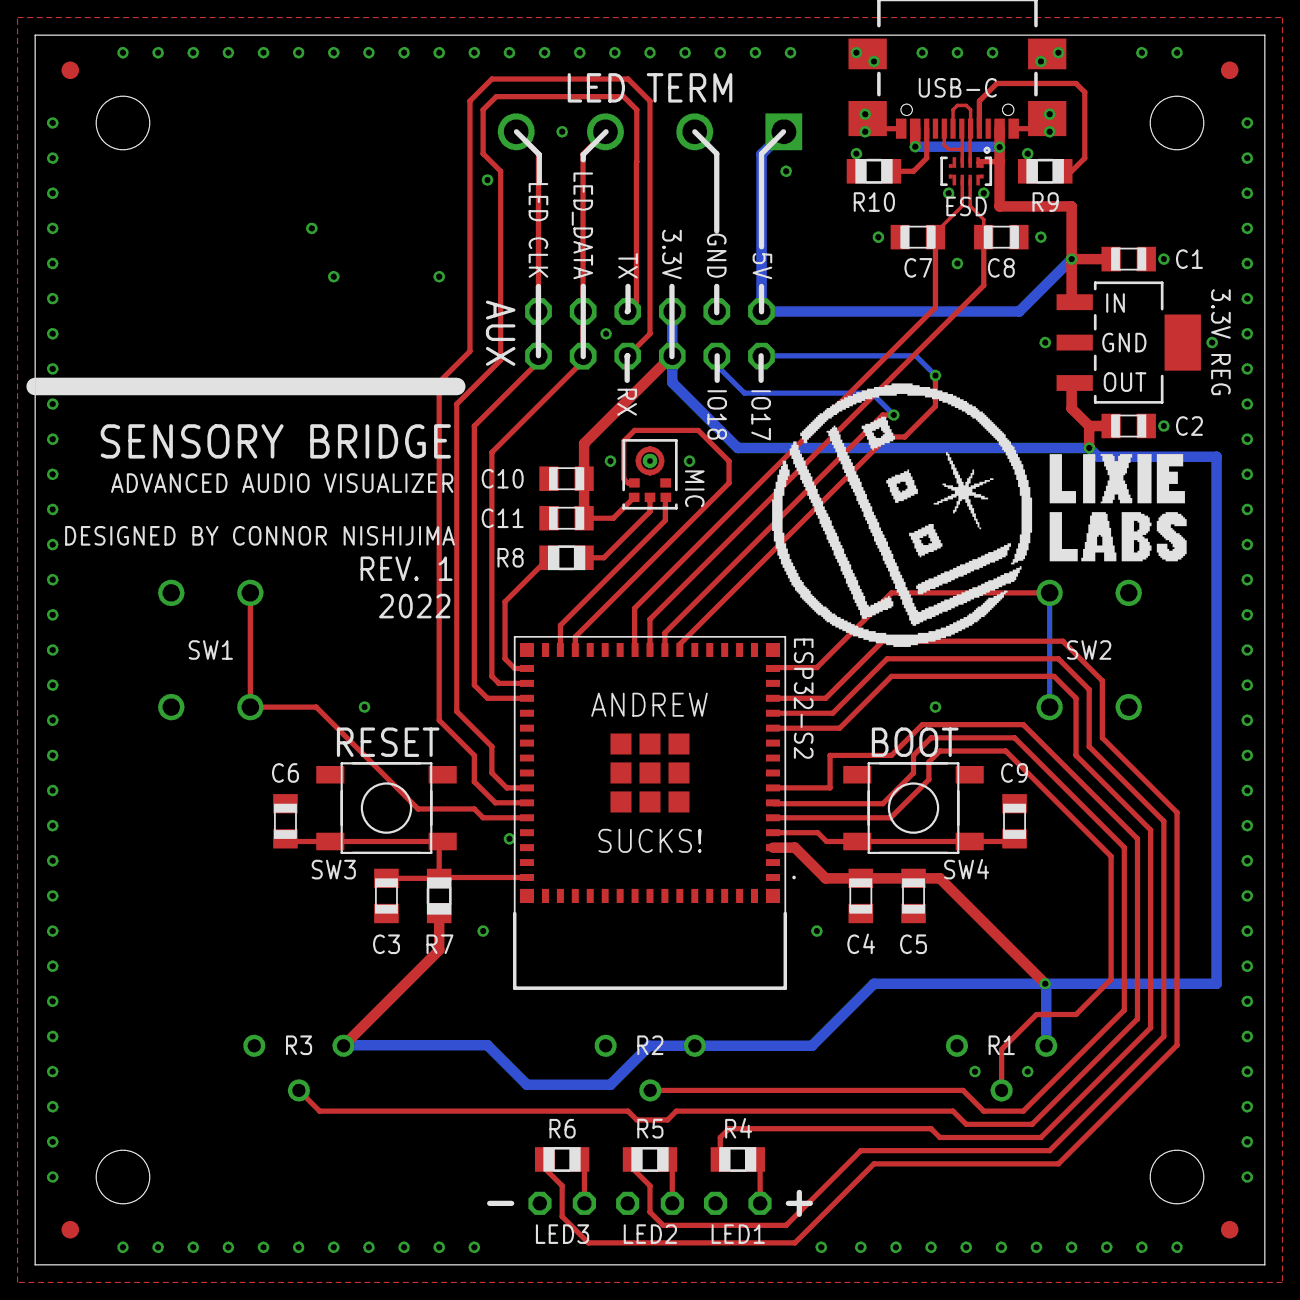
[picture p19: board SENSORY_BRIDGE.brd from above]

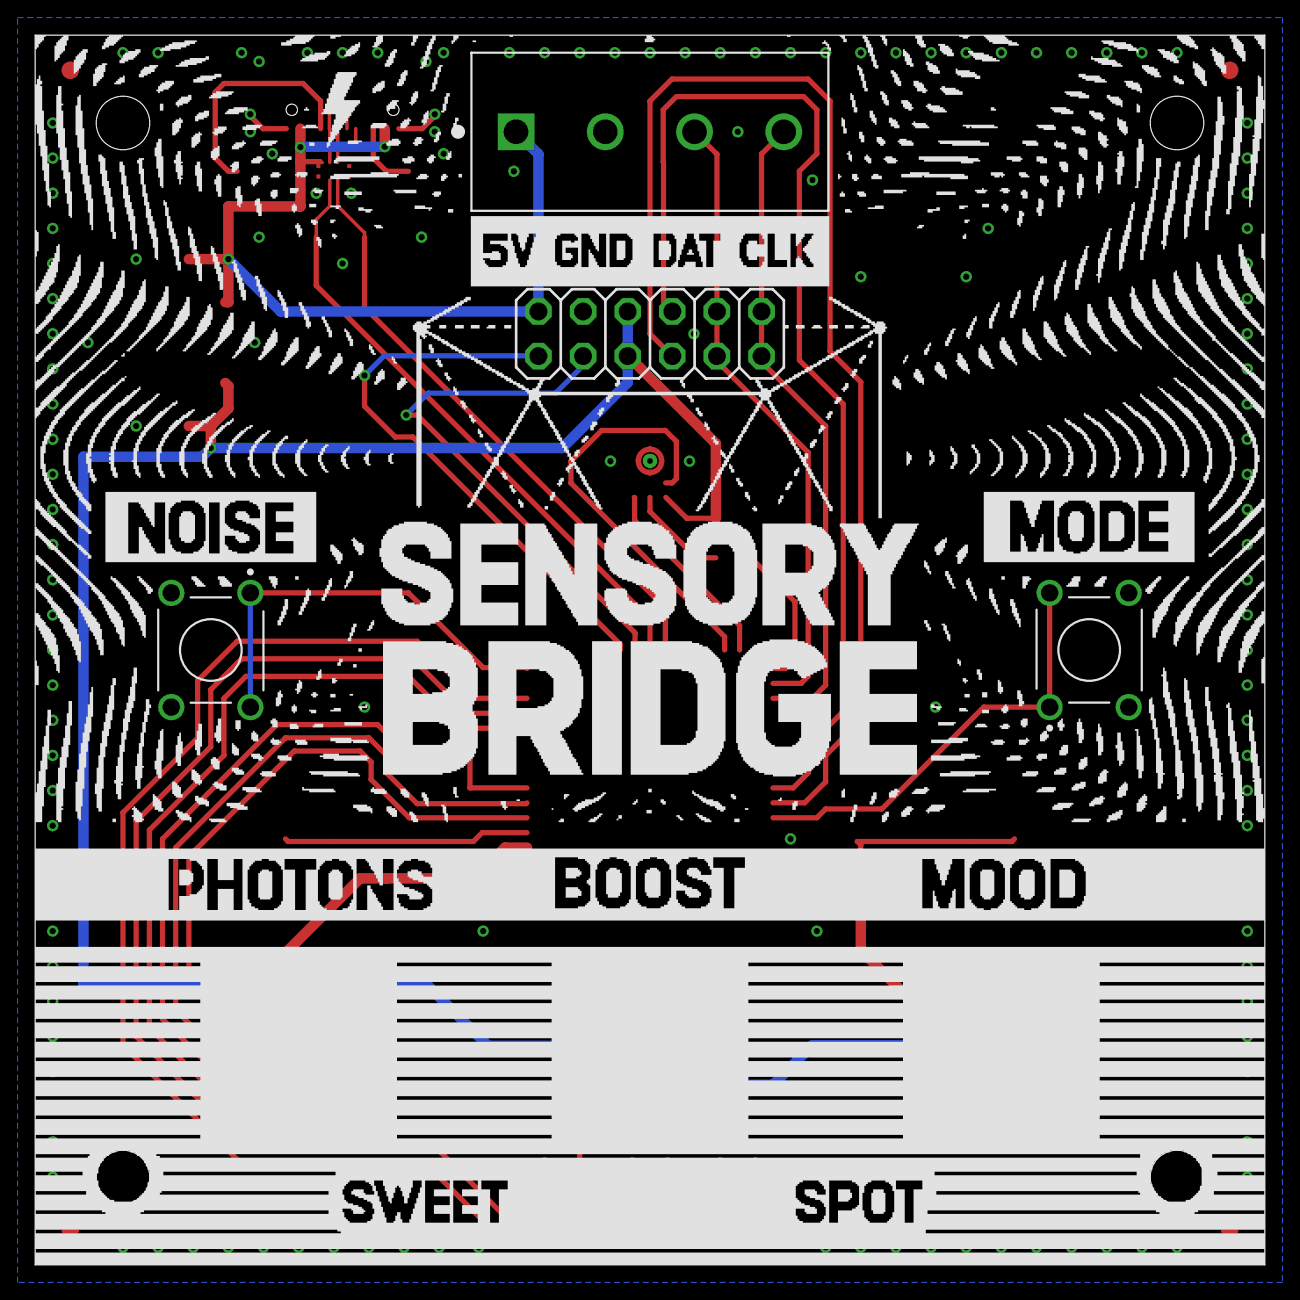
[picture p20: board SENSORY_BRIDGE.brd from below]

Board: 2 copper layers, 70.0 x 70.0 mm, 39 parts (10 on the bottom side), 32 nets.

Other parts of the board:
U$1, U$2, U$3, U$4: CIRCLE-1MM-2R

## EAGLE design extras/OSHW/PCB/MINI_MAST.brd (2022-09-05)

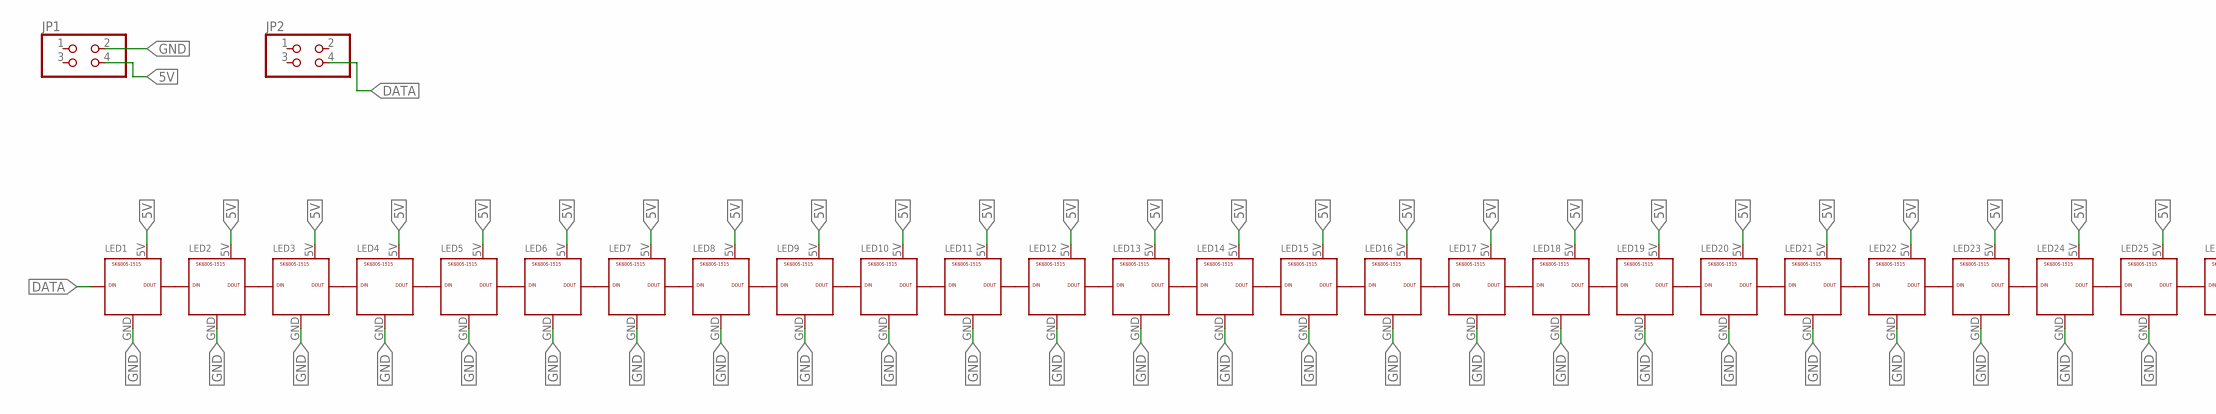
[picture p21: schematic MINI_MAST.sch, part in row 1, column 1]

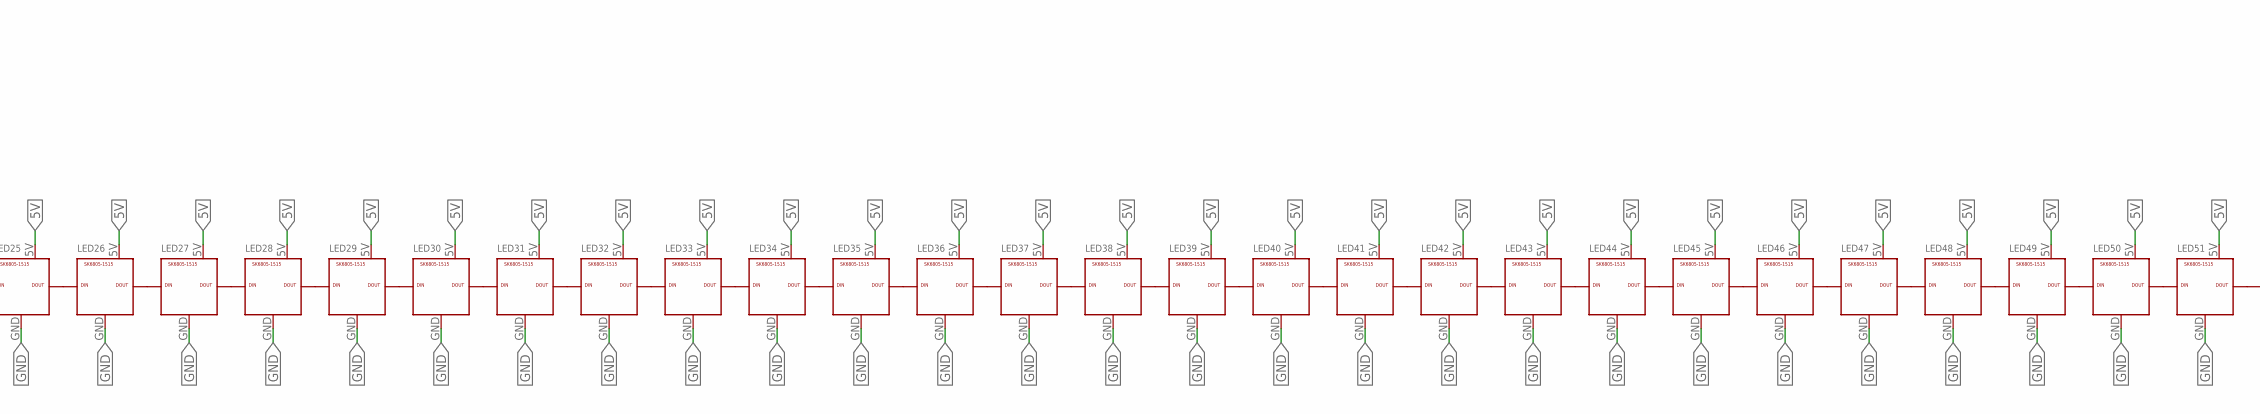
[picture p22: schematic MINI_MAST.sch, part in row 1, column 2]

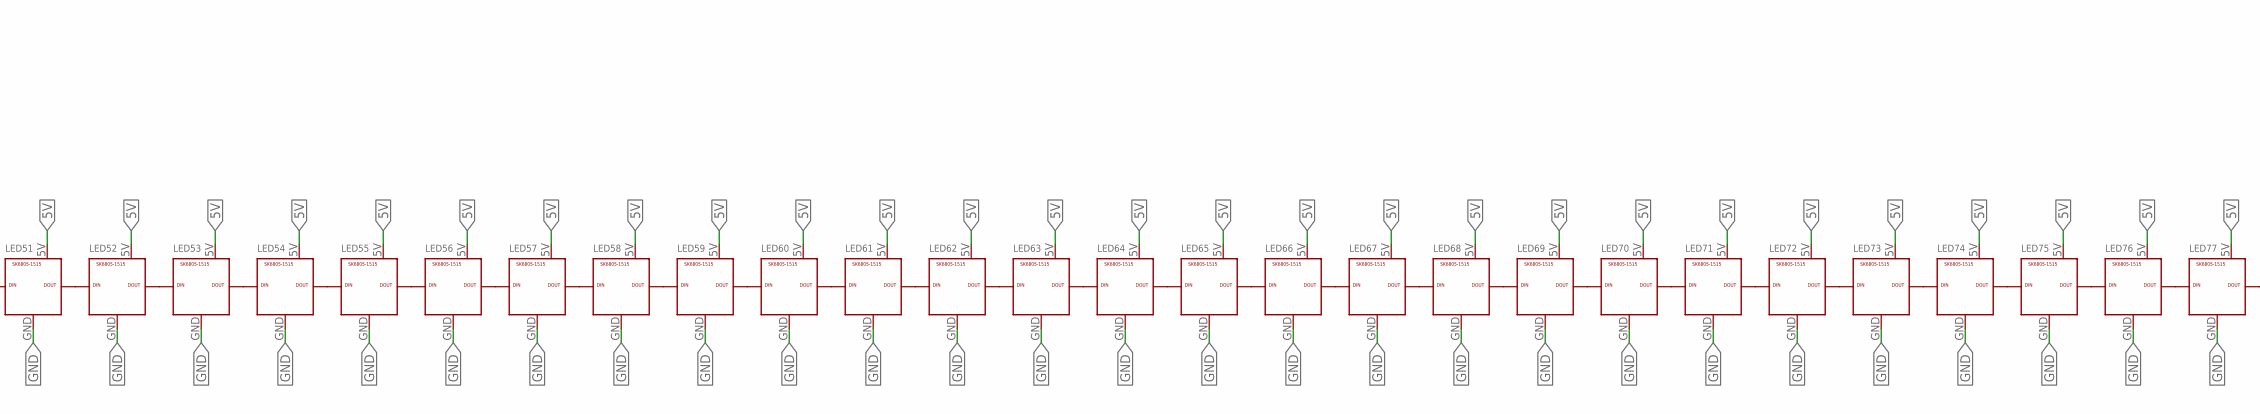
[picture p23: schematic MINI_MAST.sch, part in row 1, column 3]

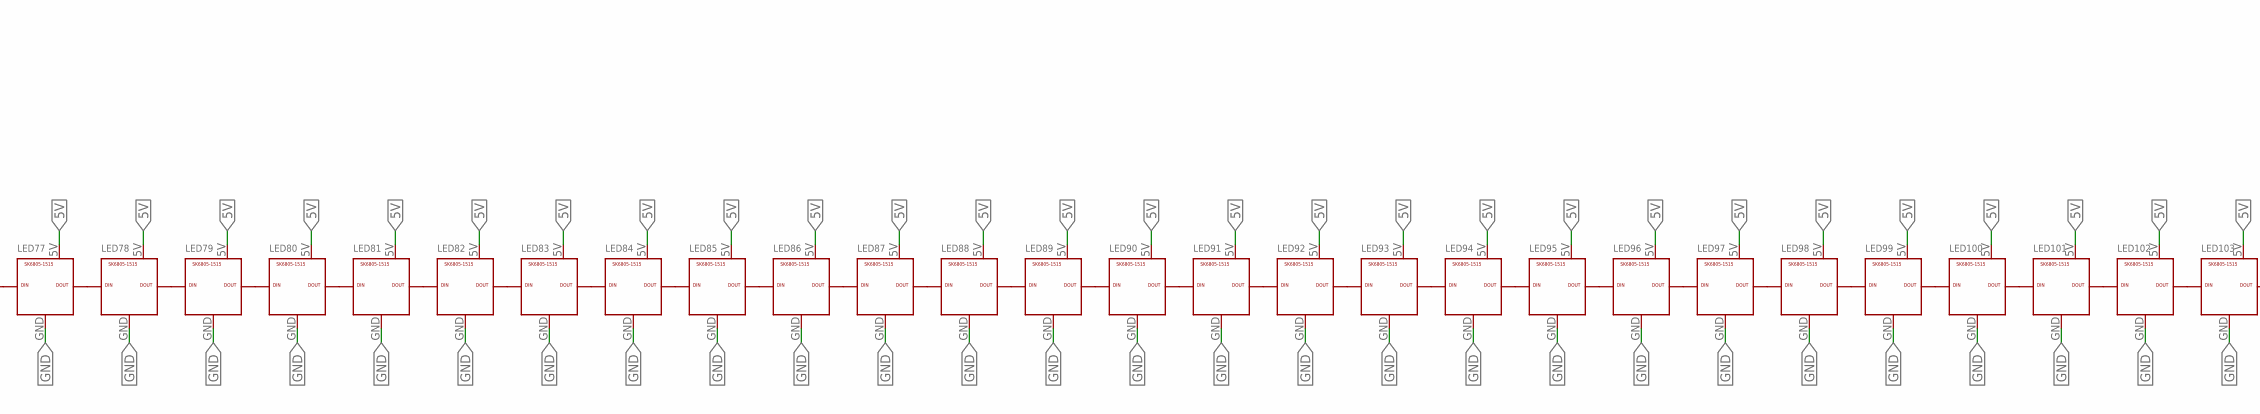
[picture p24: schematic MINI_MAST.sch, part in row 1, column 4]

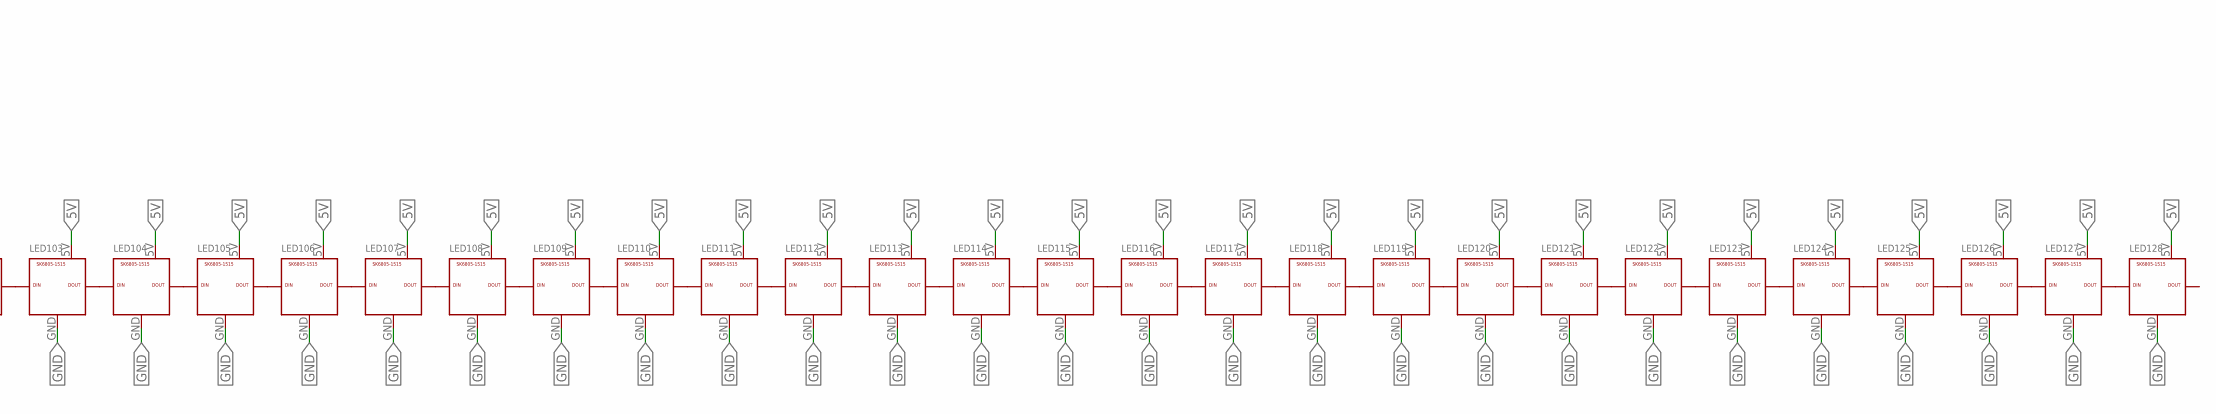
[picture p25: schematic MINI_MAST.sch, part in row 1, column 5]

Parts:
JP1, JP2: PINHD-2X2/90; 2X02/90
LED1, LED2, LED3, LED4, LED5, LED6, LED7, LED8, LED9, LED10, LED11, LED12, LED13, LED14, LED15, LED16, LED17, LED18, LED19, LED20, LED21, LED22, LED23, LED24, LED25, LED26, LED27, LED28, LED29, LED30, LED31, LED32, LED33, LED34, LED35, LED36, LED37, LED38, LED39, LED40, LED41, LED42, LED43, LED44, LED45, LED46, LED47, LED48, LED49, LED50, LED51, LED52, LED53, LED54, LED55, LED56, LED57, LED58, LED59, LED60, LED61, LED62, LED63, LED64, LED65, LED66, LED67, LED68, LED69, LED70, LED71, LED72, LED73, LED74, LED75, LED76, LED77, LED78, LED79, LED80, LED81, LED82, LED83, LED84, LED85, LED86, LED87, LED88, LED89, LED90, LED91, LED92, LED93, LED94, LED95, LED96, LED97, LED98, LED99, LED100, LED101, LED102, LED103, LED104, LED105, LED106, LED107, LED108, LED109, LED110, LED111, LED112, LED113, LED114, LED115, LED116, LED117, LED118, LED119, LED120, LED121, LED122, LED123, LED124, LED125, LED126, LED127, LED128: SK6805-1515; 1515

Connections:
5V: JP1.4, LED1.5V, LED2.5V, LED3.5V, LED4.5V, LED5.5V, LED6.5V, LED7.5V, LED8.5V, LED9.5V, LED10.5V, LED11.5V, LED12.5V, LED13.5V, LED14.5V, LED15.5V, LED16.5V, LED17.5V, LED18.5V, LED19.5V, LED20.5V, LED21.5V, LED22.5V, LED23.5V, LED24.5V, LED25.5V, LED26.5V, LED27.5V, LED28.5V, LED29.5V, LED30.5V, LED31.5V, LED32.5V, LED33.5V, LED34.5V, LED35.5V, LED36.5V, LED37.5V, LED38.5V, LED39.5V, LED40.5V, LED41.5V, LED42.5V, LED43.5V, LED44.5V, LED45.5V, LED46.5V, LED47.5V, LED48.5V, LED49.5V, LED50.5V, LED51.5V, LED52.5V, LED53.5V, LED54.5V, LED55.5V, LED56.5V, LED57.5V, LED58.5V, LED59.5V, LED60.5V, LED61.5V, LED62.5V, LED63.5V, LED64.5V, LED65.5V, LED66.5V, LED67.5V, LED68.5V, LED69.5V, LED70.5V, LED71.5V, LED72.5V, LED73.5V, LED74.5V, LED75.5V, LED76.5V, LED77.5V, LED78.5V, LED79.5V, LED80.5V, LED81.5V, LED82.5V, LED83.5V, LED84.5V, LED85.5V, LED86.5V, LED87.5V, LED88.5V, LED89.5V, LED90.5V, LED91.5V, LED92.5V, LED93.5V, LED94.5V, LED95.5V, LED96.5V, LED97.5V, LED98.5V, LED99.5V, LED100.5V, LED101.5V, LED102.5V, LED103.5V, LED104.5V, LED105.5V, LED106.5V, LED107.5V, LED108.5V, LED109.5V, LED110.5V, LED111.5V, LED112.5V, LED113.5V, LED114.5V, LED115.5V, LED116.5V, LED117.5V, LED118.5V, LED119.5V, LED120.5V, LED121.5V, LED122.5V, LED123.5V, LED124.5V, LED125.5V, LED126.5V, LED127.5V, LED128.5V
DATA: JP2.4, LED1.DIN
DATA1: LED8.DOUT, LED9.DIN
DATA2: LED24.DOUT, LED25.DIN
DATA3: LED40.DOUT, LED41.DIN
DATA4: LED56.DOUT, LED57.DIN
DATA5: LED64.DOUT, LED65.DIN
DATA6: LED72.DOUT, LED73.DIN
DATA7: LED88.DOUT, LED89.DIN
DATA8: LED104.DOUT, LED105.DIN
DATA9: LED120.DOUT, LED121.DIN
GND: JP1.2, LED1.GND, LED2.GND, LED3.GND, LED4.GND, LED5.GND, LED6.GND, LED7.GND, LED8.GND, LED9.GND, LED10.GND, LED11.GND, LED12.GND, LED13.GND, LED14.GND, LED15.GND, LED16.GND, LED17.GND, LED18.GND, LED19.GND, LED20.GND, LED21.GND, LED22.GND, LED23.GND, LED24.GND, LED25.GND, LED26.GND, LED27.GND, LED28.GND, LED29.GND, LED30.GND, LED31.GND, LED32.GND, LED33.GND, LED34.GND, LED35.GND, LED36.GND, LED37.GND, LED38.GND, LED39.GND, LED40.GND, LED41.GND, LED42.GND, LED43.GND, LED44.GND, LED45.GND, LED46.GND, LED47.GND, LED48.GND, LED49.GND, LED50.GND, LED51.GND, LED52.GND, LED53.GND, LED54.GND, LED55.GND, LED56.GND, LED57.GND, LED58.GND, LED59.GND, LED60.GND, LED61.GND, LED62.GND, LED63.GND, LED64.GND, LED65.GND, LED66.GND, LED67.GND, LED68.GND, LED69.GND, LED70.GND, LED71.GND, LED72.GND, LED73.GND, LED74.GND, LED75.GND, LED76.GND, LED77.GND, LED78.GND, LED79.GND, LED80.GND, LED81.GND, LED82.GND, LED83.GND, LED84.GND, LED85.GND, LED86.GND, LED87.GND, LED88.GND, LED89.GND, LED90.GND, LED91.GND, LED92.GND, LED93.GND, LED94.GND, LED95.GND, LED96.GND, LED97.GND, LED98.GND, LED99.GND, LED100.GND, LED101.GND, LED102.GND, LED103.GND, LED104.GND, LED105.GND, LED106.GND, LED107.GND, LED108.GND, LED109.GND, LED110.GND, LED111.GND, LED112.GND, LED113.GND, LED114.GND, LED115.GND, LED116.GND, LED117.GND, LED118.GND, LED119.GND, LED120.GND, LED121.GND, LED122.GND, LED123.GND, LED124.GND, LED125.GND, LED126.GND, LED127.GND, LED128.GND
unnamed: LED1.DOUT, LED2.DIN
unnamed: LED3.DOUT, LED4.DIN
unnamed: LED2.DOUT, LED3.DIN
unnamed: LED5.DOUT, LED6.DIN
unnamed: LED7.DOUT, LED8.DIN
unnamed: LED6.DOUT, LED7.DIN
unnamed: LED4.DOUT, LED5.DIN
unnamed: LED9.DOUT, LED10.DIN
unnamed: LED11.DOUT, LED12.DIN
unnamed: LED10.DOUT, LED11.DIN
unnamed: LED13.DOUT, LED14.DIN
unnamed: LED15.DOUT, LED16.DIN
unnamed: LED14.DOUT, LED15.DIN
unnamed: LED12.DOUT, LED13.DIN
unnamed: LED17.DOUT, LED18.DIN
unnamed: LED19.DOUT, LED20.DIN
unnamed: LED18.DOUT, LED19.DIN
unnamed: LED21.DOUT, LED22.DIN
unnamed: LED23.DOUT, LED24.DIN
unnamed: LED22.DOUT, LED23.DIN
unnamed: LED20.DOUT, LED21.DIN
unnamed: LED25.DOUT, LED26.DIN
unnamed: LED27.DOUT, LED28.DIN
unnamed: LED26.DOUT, LED27.DIN
unnamed: LED29.DOUT, LED30.DIN
unnamed: LED31.DOUT, LED32.DIN
unnamed: LED30.DOUT, LED31.DIN
unnamed: LED28.DOUT, LED29.DIN
unnamed: LED16.DOUT, LED17.DIN
unnamed: LED33.DOUT, LED34.DIN
unnamed: LED35.DOUT, LED36.DIN
unnamed: LED34.DOUT, LED35.DIN
unnamed: LED37.DOUT, LED38.DIN
unnamed: LED39.DOUT, LED40.DIN
unnamed: LED38.DOUT, LED39.DIN
unnamed: LED36.DOUT, LED37.DIN
unnamed: LED41.DOUT, LED42.DIN
unnamed: LED43.DOUT, LED44.DIN
unnamed: LED42.DOUT, LED43.DIN
unnamed: LED45.DOUT, LED46.DIN
unnamed: LED47.DOUT, LED48.DIN
unnamed: LED46.DOUT, LED47.DIN
unnamed: LED44.DOUT, LED45.DIN
unnamed: LED49.DOUT, LED50.DIN
unnamed: LED51.DOUT, LED52.DIN
unnamed: LED50.DOUT, LED51.DIN
unnamed: LED53.DOUT, LED54.DIN
unnamed: LED55.DOUT, LED56.DIN
unnamed: LED54.DOUT, LED55.DIN
unnamed: LED52.DOUT, LED53.DIN
unnamed: LED57.DOUT, LED58.DIN
unnamed: LED59.DOUT, LED60.DIN
unnamed: LED58.DOUT, LED59.DIN
unnamed: LED61.DOUT, LED62.DIN
unnamed: LED63.DOUT, LED64.DIN
unnamed: LED62.DOUT, LED63.DIN
unnamed: LED60.DOUT, LED61.DIN
unnamed: LED48.DOUT, LED49.DIN
unnamed: LED32.DOUT, LED33.DIN
unnamed: LED65.DOUT, LED66.DIN
unnamed: LED67.DOUT, LED68.DIN
unnamed: LED66.DOUT, LED67.DIN
unnamed: LED69.DOUT, LED70.DIN
unnamed: LED71.DOUT, LED72.DIN
unnamed: LED70.DOUT, LED71.DIN
unnamed: LED68.DOUT, LED69.DIN
unnamed: LED73.DOUT, LED74.DIN
unnamed: LED75.DOUT, LED76.DIN
unnamed: LED74.DOUT, LED75.DIN
unnamed: LED77.DOUT, LED78.DIN
unnamed: LED79.DOUT, LED80.DIN
unnamed: LED78.DOUT, LED79.DIN
unnamed: LED76.DOUT, LED77.DIN
unnamed: LED81.DOUT, LED82.DIN
unnamed: LED83.DOUT, LED84.DIN
unnamed: LED82.DOUT, LED83.DIN
unnamed: LED85.DOUT, LED86.DIN
unnamed: LED87.DOUT, LED88.DIN
unnamed: LED86.DOUT, LED87.DIN
unnamed: LED84.DOUT, LED85.DIN
unnamed: LED89.DOUT, LED90.DIN
unnamed: LED91.DOUT, LED92.DIN
unnamed: LED90.DOUT, LED91.DIN
unnamed: LED93.DOUT, LED94.DIN
unnamed: LED95.DOUT, LED96.DIN
unnamed: LED94.DOUT, LED95.DIN
unnamed: LED92.DOUT, LED93.DIN
unnamed: LED80.DOUT, LED81.DIN
unnamed: LED97.DOUT, LED98.DIN
unnamed: LED99.DOUT, LED100.DIN
unnamed: LED98.DOUT, LED99.DIN
unnamed: LED101.DOUT, LED102.DIN
unnamed: LED103.DOUT, LED104.DIN
unnamed: LED102.DOUT, LED103.DIN
unnamed: LED100.DOUT, LED101.DIN
unnamed: LED105.DOUT, LED106.DIN
unnamed: LED107.DOUT, LED108.DIN
unnamed: LED106.DOUT, LED107.DIN
unnamed: LED109.DOUT, LED110.DIN
unnamed: LED111.DOUT, LED112.DIN
unnamed: LED110.DOUT, LED111.DIN
unnamed: LED108.DOUT, LED109.DIN
unnamed: LED113.DOUT, LED114.DIN
unnamed: LED115.DOUT, LED116.DIN
unnamed: LED114.DOUT, LED115.DIN
unnamed: LED117.DOUT, LED118.DIN
unnamed: LED119.DOUT, LED120.DIN
unnamed: LED118.DOUT, LED119.DIN
unnamed: LED116.DOUT, LED117.DIN
unnamed: LED121.DOUT, LED122.DIN
unnamed: LED123.DOUT, LED124.DIN
unnamed: LED122.DOUT, LED123.DIN
unnamed: LED125.DOUT, LED126.DIN
unnamed: LED127.DOUT, LED128.DIN
unnamed: LED126.DOUT, LED127.DIN
unnamed: LED124.DOUT, LED125.DIN
unnamed: LED112.DOUT, LED113.DIN
unnamed: LED96.DOUT, LED97.DIN

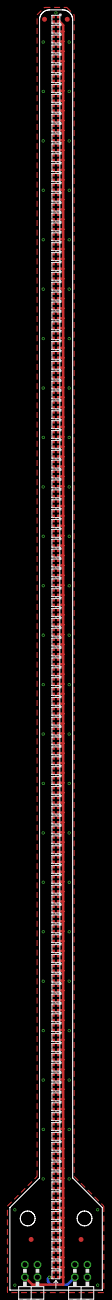
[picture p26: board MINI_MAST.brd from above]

Board: 2 copper layers, 18.7 x 259.0 mm, 134 parts (0 on the bottom side), 130 nets.

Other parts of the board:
U$1, U$2, U$3, U$4: CIRCLE-1MM-2R

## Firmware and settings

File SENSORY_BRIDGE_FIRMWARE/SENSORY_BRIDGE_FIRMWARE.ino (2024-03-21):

/*------------------------------------------------------------------------------------------------------------------------------------

   ######   ########  ##       ##   ######     ####    #######   ##    ##       ######    #######   ####  #######    ######   ########
  ##    ##  ##        ###      ##  ##    ##   ##  ##   ##    ##  ###  ###       ##   ##   ##    ##   ##   ##    ##  ###  ###  ##
  ##    ##  ##        ####     ##  ##    ##  ##    ##  ##    ##   ##  ##        ##    ##  ##    ##   ##   ##    ##  ##    ##  ##
   ##       ##        ##  ##   ##   ##       ##    ##  ##   ###   ##  ##        ##   ##   ##   ###   ##   ##    ##  ##        ##
     ##     ######    ##   ##  ##     ##     ##    ##  ######      ####         ######    ######     ##   ##    ##  ##        ######
       ##   ##        ##    ## ##       ##   ##    ##  ##    ##     ##          ##   ##   ##    ##   ##   ##    ##  ##   ###  ##
  ##    ##  ##        ##     ####  ##    ##  ##    ##  ##    ##     ##          ##    ##  ##    ##   ##   ##    ##  ##    ##  ##
  ##    ##  ##        ##      ###  ##    ##   ##  ##   ##    ##     ##          ##   ##   ##    ##   ##   ##    ##  ###  ###  ##
   ######   ########  ##       ##   ######     ####    ##    ##     ##          ######    ##    ##  ####  #######    ######   ########

  by @lixielabs (2022 - 2023)

  ####################################################################

  Welcome to the Sensory Bridge firmware files!

  WARNING:

    If the above ASCII art is not showing "SENSORY BRIDGE" correctly,
    you're probably on < Arduino 2.1.0. This means you'll need to make a
    few changes for this firmware to work.

  ####################################################################

  1. DISABLE WORD WRAPPING -------------------------------------------

    (This will guarantee code and docs are more readable)

  - In the Arduino 2.0.x IDE, hit F1
  - In the textbox that appears, type "wrap"
  - You'll see a result for "View - Toggle Word Wrap"
  - Click this item
  - Repeat at least once until buggy word-wrapping is actually disabled
  - This is a painful change that the IDE 1.x didn't do
      (In fact no other IDE I've ever used does this, ugh.)

  2. DISABLE DEFAULT COMPILATION WARNING BEHAVIOR --------------------

    (This will make the firmware actually usable)

  - In the Arduino 2.0.x IDE, click "File > Preferences"
  - Set "Compiler Warnings" to "Default"
  - This is because some dependencies below trigger ignorable warnings
  - Arduino IDE 2.0.0 treats all warnings as errors by default.
  - This is a *painful* change that the IDE 1.x didn't do

  Anyways, let's begin!

  ---------------------------------------------------------------------*/

#define FIRMWARE_VERSION 40101  // Try "V" on the Serial port for this!
//                       MmmPP     M = Major version, m = Minor version, P = Patch version
//                                 (i.e 3.5.4 would be 30504)

// Lightshow modes by name -----------------------------------------------------------
enum lightshow_modes {
  LIGHT_MODE_GDFT,  // ------------- GDFT - Goertzel-based Discrete Fourier Transform
  //                                 (I made this name up. Saved you a search.)
  LIGHT_MODE_GDFT_CHROMAGRAM,       // -- Chromagram of GDFT
  LIGHT_MODE_GDFT_CHROMAGRAM_DOTS,  // -- Chromagram of GDFT
  LIGHT_MODE_BLOOM,                 // -- Bloom Mode
  LIGHT_MODE_VU_DOT,                // -- Not a real VU for any measurement sake, just a dance-y LED show
  LIGHT_MODE_KALEIDOSCOPE,          // -- Three color channels 2D Perlin noise affected by the onsets of low, mid and high pitches

  NUM_MODES  // used to know the length of this list if it changes in the future
};

// External dependencies -------------------------------------------------------------
#include <WiFi.h>         // Needed for Station Mode
#include <esp_now.h>      // P2P wireless communication library (p2p.h below)
#include <esp_random.h>   // RNG Functions
#include <FastLED.h>      // Handles LED color data and display
#include <FS.h>           // Filesystem functions (bridge_fs.h below)
#include <LittleFS.h>     // LittleFS implementation
#include <Ticker.h>       // Scheduled tasks library
#include <USB.h>          // USB Connection handling
#include <FirmwareMSC.h>  // Allows firmware updates via USB MSC
#include <FixedPoints.h>
#include <FixedPointsCommon.h>

// Include Sensory Bridge firmware files, sorted high to low, by boringness ;) -------
#include "strings.h"          // Strings for printing
#include "user_config.h"      // Nothing for now
#include "constants.h"        // Global constants
#include "globals.h"          // Global variables
#include "presets.h"          // Configuration presets by name
#include "bridge_fs.h"        // Filesystem access (save/load configuration)
#include "utilities.h"        // Misc. math and other functions
#include "i2s_audio.h"        // I2S Microphone audio capture
#include "led_utilities.h"    // LED color/transform utility functions
#include "noise_cal.h"        // Background noise removal
#include "p2p.h"              // Sensory Sync handling
#include "buttons.h"          // Watch the status of buttons
#include "knobs.h"            // Watch the status of knobs...
#include "serial_menu.h"      // Watch the Serial port... *sigh*
#include "system.h"           // Watch how fast I can check if settings were updated... yada yada..
#include "GDFT.h"             // Conversion to (and post-processing of) frequency data! (hey, something cool!)
#include "lightshow_modes.h"  // --- FINALLY, the FUN STUFF!

// Setup, runs only one time ---------------------------------------------------------
void setup() {
  init_system();  // (system.h) Initialize all hardware and arrays

  // Create thread specifically for LED updates
  xTaskCreatePinnedToCore(led_thread, "led_task", 8192, NULL, tskIDLE_PRIORITY + 1, &led_task, 1);
}

// Loop, runs forever after setup() --------------------------------------------------
void loop() {
  uint32_t t_now_us = micros();        // Timestamp for this loop, used by some core functions
  uint32_t t_now = t_now_us / 1000.0;  // Millisecond version

  function_id = 0;     // These are for debug_function_timing() in system.h to see what functions take up the most time
  check_knobs(t_now);  // (knobs.h)
  // Check if the knobs have changed

  function_id = 1;
  check_buttons(t_now);  // (buttons.h)
  // Check if the buttons have changed

  function_id = 2;
  check_settings(t_now);  // (system.h)
  // Check if the settings have changed

  function_id = 3;
  check_serial(t_now);  // (serial_menu.h)
  // Check if UART commands are available

  function_id = 4;
  run_p2p();  // (p2p.h)
  // Process P2P network packets to synchronize units

  function_id = 5;
  acquire_sample_chunk(t_now);  // (i2s_audio.h)
  // Capture a frame of I2S audio (holy crap, FINALLY something about sound)

  function_id = 6;
  run_sweet_spot();  // (led_utilities.h)
  // Based on the current audio volume, alter the Sweet Spot indicator LEDs

  // Calculates audio loudness (VU) using RMS, adjusting for noise floor based on calibration
  calculate_vu();

  function_id = 7;
  process_GDFT();  // (GDFT.h)
  // Execute GDFT and post-process
  // (If you're wondering about that weird acronym, check out the source file)

  // Watches the rate of change in the Goertzel bins to guide decisions for auto-color shifting
  calculate_novelty(t_now);

  if (CONFIG.AUTO_COLOR_SHIFT == true) {  // Automatically cycle color based on density of positive spectral changes
    // Use the "novelty" findings of the above function to affect color shifting when auto-color shifts are enabled
    process_color_shift();
  } else {
    hue_position = 0;
    hue_shifting_mix = -0.35;
  }

  function_id = 8;
  //lookahead_smoothing();  // (GDFT.h)
  // Peek at upcoming frames to study/prevent flickering

  function_id = 8;
  log_fps(t_now_us);  // (system.h)
  // Log the audio system FPS

  if (debug_mode == true) {
    function_id = 31;
    debug_function_timing(t_now);
  }

  yield();  // Otherwise the ESP32 will collapse into a black hole or something
}

// Run the lights in their own thread! -------------------------------------------------------------
void led_thread(void* arg) {
  while (true) {
    if (led_thread_halt == false) {                                             // If we're not gathering ambient noise data
      if (mode_transition_queued == true || noise_transition_queued == true) {  // If transition queued
        run_transition_fade();                                                  // (led_utilities.h) Fade to black between modes
      }

      get_smooth_spectrogram();
      make_smooth_chromagram();

      // Based on the value of CONFIG.LIGHTSHOW_MODE, we call a
      // different rendering function from lightshow_modes.h:

      if (CONFIG.LIGHTSHOW_MODE == LIGHT_MODE_GDFT) {
        light_mode_gdft();  // (lightshow_modes.h) GDFT spectrogram display
      } else if (CONFIG.LIGHTSHOW_MODE == LIGHT_MODE_GDFT_CHROMAGRAM) {
        light_mode_chromagram_gradient();  //light_mode_chromagram_gradient();  // (lightshow_modes.h) GDFT chromagram display
      } else if (CONFIG.LIGHTSHOW_MODE == LIGHT_MODE_GDFT_CHROMAGRAM_DOTS) {
        light_mode_chromagram_dots();  //light_mode_chromagram_dots();  // (lightshow_modes.h) GDFT chromagram display
      } else if (CONFIG.LIGHTSHOW_MODE == LIGHT_MODE_BLOOM) {
        light_mode_bloom();  // (lightshow_modes.h) Bloom Mode display
      } else if (CONFIG.LIGHTSHOW_MODE == LIGHT_MODE_VU_DOT) {
        light_mode_vu_dot();  // (lightshow_modes.h) VU Mode display (dot version)
      } else if (CONFIG.LIGHTSHOW_MODE == LIGHT_MODE_KALEIDOSCOPE) {
        light_mode_kaleidoscope();  // (lightshow_modes.h) Kaleidoscope Mode display
      }

      if (CONFIG.PRISM_COUNT > 0) {
        apply_prism_effect(CONFIG.PRISM_COUNT, 0.25);
      }

      // Render bulb filter
      if (CONFIG.BULB_OPACITY > 0.00) {
        render_bulb_cover();
      }

      // If forcing monochromatic incandescent output
      if (CONFIG.INCANDESCENT_MODE == true) {
        for (uint8_t i = 0; i < NATIVE_RESOLUTION; i++) {
          leds_16[i] = adjust_hue_and_saturation(leds_16[i], 0.05, 0.95);
        }
      }

      if (CONFIG.MIRROR_ENABLED == false) {  // Mirroring logic
        unmirror();
      }

      show_leds();  // This sends final RGB data to the LEDS (led_utilities.h)
      LED_FPS = FastLED.getFPS(); 
    }
    vTaskDelay(1);
  }
}

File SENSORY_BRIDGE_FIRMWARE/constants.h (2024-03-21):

// AUDIO #######################################################

#define SERIAL_BAUD 230400
#define DEFAULT_SAMPLE_RATE 12800
#define SAMPLE_HISTORY_LENGTH 4096

// Don't change this unless you're willing to do a lot of other work on the code :/
#define NATIVE_RESOLUTION 128
#define NUM_FREQS 64
#define NUM_ZONES 2

#define I2S_PORT I2S_NUM_0

#define SPECTRAL_HISTORY_LENGTH 5

#define MAX_DOTS 128

enum reserved_dots {
  GRAPH_NEEDLE,
  GRAPH_DOT_1,
  GRAPH_DOT_2,
  GRAPH_DOT_3,
  GRAPH_DOT_4,
  GRAPH_DOT_5,
  RIPPLE_LEFT,
  RIPPLE_RIGHT,

  RESERVED_DOTS
};

enum knob_names {
  K_NONE,
  K_PHOTONS,
  K_CHROMA,
  K_MOOD
};

struct CRGB16 {  // Unsigned Q8.8 Fixed-point color channels
  SQ15x16 r;
  SQ15x16 g;
  SQ15x16 b;
};

struct DOT {
  SQ15x16 position;
  SQ15x16 last_position;
};

struct KNOB {
  SQ15x16  value;
  SQ15x16  last_value;
  SQ15x16  change_rate;
  uint32_t last_change;
};

const float notes[] = {
  55.00000, 58.27047, 61.73541, 65.40639, 69.29566, 73.41619, 77.78175, 82.40689, 87.30706, 92.49861, 97.99886, 103.8262,
  110.0000, 116.5409, 123.4708, 130.8128, 138.5913, 146.8324, 155.5635, 164.8138, 174.6141, 184.9972, 195.9977, 207.6523,
  220.0000, 233.0819, 246.9417, 261.6256, 277.1826, 293.6648, 311.1270, 329.6276, 349.2282, 369.9944, 391.9954, 415.3047,
  440.0000, 466.1638, 493.8833, 523.2511, 554.3653, 587.3295, 622.2540, 659.2551, 698.4565, 739.9888, 783.9909, 830.6094,
  880.0000, 932.3275, 987.7666, 1046.502, 1108.731, 1174.659, 1244.508, 1318.510, 1396.913, 1479.978, 1567.982, 1661.219,
  1760.000, 1864.655, 1975.533, 2093.005, 2217.461, 2349.318, 2489.016, 2637.020, 2793.825, 2959.956, 3135.964, 3322.437,
  3520.000, 3729.310, 3951.065, 4186.009, 4434.922, 4698.636, 4978.032, 5274.041, 5587.652, 5919.911, 6271.927, 6644.875,
  7040.000, 7458.620, 7902.130, 8372.018, 8869.844, 9397.272, 9956.064, 10548.08, 11175.30, 11839.82, 12543.85, 13289.75
};

// GPIO PINS #######################################################

#define PHOTONS_PIN 1
#define CHROMA_PIN 2
#define MOOD_PIN 3

#define I2S_BCLK_PIN 33
#define I2S_LRCLK_PIN 34
#define I2S_DIN_PIN 35

#define LED_DATA_PIN 36
#define LED_CLOCK_PIN 37

#define RNG_SEED_PIN 10

#define NOISE_CAL_PIN 11
#define MODE_PIN 45

#define SWEET_SPOT_LEFT_PIN 7
#define SWEET_SPOT_CENTER_PIN 8
#define SWEET_SPOT_RIGHT_PIN 9

// OTHER #######################################################

const SQ15x16 dither_table[4] = {
  0.25,
  0.50,
  0.75,
  1.00
  /*
  0.166666,
  0.333333,
  0.500000,
  0.666666,
  0.833333,
  1.000000
  */
};

SQ15x16 note_colors[12] = {
  0.0000,
  0.0833,
  0.1666,
  0.2499,
  0.3333,
  0.4166,
  0.4999,
  0.5833,
  0.6666,
  0.7499,
  0.8333,
  0.9166
};

const SQ15x16 hue_lookup[64][3] = {
  { 1.0000, 0.0000, 0.0000 },
  { 0.9608, 0.0392, 0.0000 },
  { 0.9176, 0.0824, 0.0000 },
  { 0.8745, 0.1255, 0.0000 },
  { 0.8314, 0.1686, 0.0000 },
  { 0.7922, 0.2078, 0.0000 },
  { 0.7490, 0.2510, 0.0000 },
  { 0.7059, 0.2941, 0.0000 },
  { 0.6706, 0.3333, 0.0000 },
  { 0.6706, 0.3725, 0.0000 },
  { 0.6706, 0.4157, 0.0000 },
  { 0.6706, 0.4588, 0.0000 },
  { 0.6706, 0.5020, 0.0000 },
  { 0.6706, 0.5412, 0.0000 },
  { 0.6706, 0.5843, 0.0000 },
  { 0.6706, 0.6275, 0.0000 },
  { 0.6706, 0.6667, 0.0000 },
  { 0.5882, 0.7059, 0.0000 },
  { 0.5059, 0.7490, 0.0000 },
  { 0.4196, 0.7922, 0.0000 },
  { 0.3373, 0.8353, 0.0000 },
  { 0.2549, 0.8745, 0.0000 },
  { 0.1686, 0.9176, 0.0000 },
  { 0.0863, 0.9608, 0.0000 },
  { 0.0000, 1.0000, 0.0000 },
  { 0.0000, 0.9608, 0.0392 },
  { 0.0000, 0.9176, 0.0824 },
  { 0.0000, 0.8745, 0.1255 },
  { 0.0000, 0.8314, 0.1686 },
  { 0.0000, 0.7922, 0.2078 },
  { 0.0000, 0.7490, 0.2510 },
  { 0.0000, 0.7059, 0.2941 },
  { 0.0000, 0.6706, 0.3333 },
  { 0.0000, 0.5882, 0.4157 },
  { 0.0000, 0.5059, 0.4980 },
  { 0.0000, 0.4196, 0.5843 },
  { 0.0000, 0.3373, 0.6667 },
  { 0.0000, 0.2549, 0.7490 },
  { 0.0000, 0.1686, 0.8353 },
  { 0.0000, 0.0863, 0.9176 },
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
};

#define SWEET_SPOT_LEFT_CHANNEL 0
#define SWEET_SPOT_CENTER_CHANNEL 1
#define SWEET_SPOT_RIGHT_CHANNEL 2

#define TWOPI 6.28318530
#define FOURPI 12.56637061
#define SIXPI 18.84955593

enum led_types {
  LED_NEOPIXEL,
  LED_NEOPIXEL_X2,
  LED_DOTSTAR
};

CRGB16 incandescent_lookup = { 1.0000, 0.4453, 0.1562 };

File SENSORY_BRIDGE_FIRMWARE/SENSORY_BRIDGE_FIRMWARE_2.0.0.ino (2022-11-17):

/*----------------------------------------

  ==      ===        ==  =======  ===      =====    ====       ===  ====  =======      ====       ===    ==       ====      ===        =
  =  ====  ==  ========   ======  ==  ====  ===  ==  ===  ====  ==   ==   =======  ===  ===  ====  ===  ===  ====  ==   ==   ==  =======
  =  ====  ==  ========    =====  ==  ====  ==  ====  ==  ====  ===  ==  ========  ====  ==  ====  ===  ===  ====  ==  ====  ==  =======
  ==  =======  ========  ==  ===  ===  =======  ====  ==  ===   ===  ==  ========  ===  ===  ===   ===  ===  ====  ==  ========  =======
  ====  =====      ====  ===  ==  =====  =====  ====  ==      ======    =========      ====      =====  ===  ====  ==  ========      ===
  ======  ===  ========  ====  =  =======  ===  ====  ==  ====  =====  ==========  ===  ===  ====  ===  ===  ====  ==  ===   ==  =======
  =  ====  ==  ========  =====    ==  ====  ==  ====  ==  ====  =====  ==========  ====  ==  ====  ===  ===  ====  ==  ====  ==  =======
  =  ====  ==  ========  ======   ==  ====  ===  ==  ===  ====  =====  ==========  ===  ===  ====  ===  ===  ====  ==   ==   ==  =======
  ==      ===        ==  =======  ===      =====    ====  ====  =====  ==========      ====  ====  ==    ==       ====      ===        =

  Welcome to the Sensory Bridge firmware files!
  
  If the above ASCII art is not showing "SENSORY BRIDGE" correctly in
  the negative space, you're probably on Arduino 2.0.x. This means
  you'll need to make a few changes for this firmware to work.

  1. DISABLE DEFAULT COMPILATION WARNING BEHAVIOR --------------------

    (This will make the firmware actually usable)

  - In the Arduino 2.0.x IDE, click "File > Preferences"
  - Set "Compiler Warnings" to "Default"
  - This is because some dependencies below trigger ignorable warnings
  - Arduino IDE 2.0.0 treats all warnings as errors by default.

  2. DISABLE WORD WRAPPING -------------------------------------------

    (This will guarantee code and docs more readable)

  - In the Arduino 2.0.x IDE, hit F1
  - In the textbox that appears, type "wrap"
  - You'll see a result for "View - Toggle Word Wrap"
  - Click this item
  - Repeat at least once until buggy word-wrapping is actually disabled

---------------------------------------------------------------------*/

#define FIRMWARE_VERSION "2.0.0" // Try "V" on the Serial port for this!

// Lightshow modes by name
enum lightshow_modes {
  DUET_MODE, // -------- FFT with linear scaling
  DUET_MODE_LOG, // ---- FFT with log scaling
  BLOOM_MODE, // ------- Slow Bloom Mode
  BLOOM_MODE_FAST, // -- Fast Bloom Mode
  WAVEFORM_MODE, // ---- Waveform is shown using LED brightness
  VU_MODE, // ---------- Not a real VU for any measurement sake, just a dance-y LED bar
  VU_MODE_DOT, // ------ Alternate VU display mode - dot with motion blur

  NUM_MODES  // used to know the length of this list if it changes
};

// External dependencies --------------------------------------------------------
#include <WiFi.h> // ------ Needed for Station Mode
#include <esp_now.h> // --- P2P wireless communication library
#include <FastLED.h> // --- Handles LED color data and display
#include <FS.h> // -------- Filesystem functions
#include <LittleFS.h> // -- LittleFS implementation
#include <Ticker.h> // ---- Scheduled tasks library

// Include Sensory Bridge firmware files ----------------------------------------
#include "ESP32_fft.h" // -------- Fast time to frequency domain conversion
#include "hardware_config.h" // -- LED strip length
#include "constants.h" // -------- Global constants
#include "globals.h" // ---------- Global variables
#include "bridge_fs.h" // -------- Filesystem access (save/load configuration)
#include "led_utilities.h" // ---- LED color/transform utility functions
#include "i2s.h" // -------------- I2S Microphone audio capture
#include "fft_parser.h" // ------- Conversion to (and post-processing) of FFT data
#include "noise_cal.h" // -------- Background noise removal
#include "p2p.h" // -------------- Sensory Sync handling
#include "sweet_spot.h" // ------- Drive sweet spot LEDs
#include "buttons.h" // ---------- Watch the status of buttons
#include "knobs.h" // ------------ Watch the status of knobs...
#include "serial_menu.h" // ------ Watch the Serial port... *sigh*
#include "system.h" // ----------- Watch how fast I can check if settings were updated... yada yada..
#include "lightshow_modes.h" // -- FINALLY, the FUN STUFF!

void setup() {
  init_system();  // (system.h) Initialize all hardware and arrays
}

void loop() {
  uint32_t t_now = millis();  // Timestamp for this loop, used by some core functions

  function_id = 0;  // These are for debug_function_timing(), to see what functions take up the most time
  check_knobs(t_now); // (knobs.h)
  // Check if the knobs have changed

  function_id = 1;
  check_buttons(t_now); // (buttons.h)
  // Check if the buttons have changed

  function_id = 2;
  check_settings(t_now); // (settings.h)
  // Check if the settings have changed

  function_id = 3;
  check_serial(t_now); // (serial_menu.h)
  // Check if UART commands are available

  function_id = 4;
  run_p2p(); // (p2p.h)
  // Process P2P network packets to synchronize units

  function_id = 5;
  capture_audio(); // (i2s.h)
  // Capture a frame of I2S audio

  function_id = 6;
  process_fft(); // (fft_parser.h)
  // Execute FFT and post-process

  function_id = 7;
  fft_lookahead_smoothing(); // (fft_parser.h)
  // Peek at upcoming frames to study/prevent flickering

  function_id = 8;
  run_noise_cal(t_now); // (noise_cal.h)
  // Run the noise calibration, if in that state

  function_id = 9;
  run_leds(); // (this file, below)
  // Run the lightshow functions

  function_id = 10;
  run_sweet_spot(); // (sweet_spot.h)
  // Run the Sweet Spot LEDs

#ifdef DEBUG_MODE
  function_id = 11;
  debug_function_timing(t_now); // (system.h)
  // Print how many times the functions were seen running in a 30 second window
#endif
}
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

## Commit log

2022-09-04 RC1 Update
    [configuration.h]
2022-09-05 Added OSHW
    [MINI_MAST.brd, MINI_MAST.sch, SENSORY_BRIDGE.brd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]
2022-09-05 Added OSHW files
    [MINI_MAST.brd, MINI_MAST.sch, MINI_MAST_MOUNT.stl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]
2022-09-11 Final 1.0.0 Changes
    [configuration.h]
2022-09-22 Folder Structure Fix
    [configuration.h]
2022-10-04 Update fft.h per connornishijima/SensoryBridge#9
2022-10-07 Added USB PID code
    Cool, cool cool cool
2022-10-07 Documentation update
    [configuration.h]
2022-10-07 Fixed LED definition to be more flexible with color ordering
    [system.h]
2022-11-17 Firmware 2.0.0 Upload
    [configuration.h]
2022-11-17 Added new titles and fixed .ino name
    [SENSORY_BRIDGE_FIRMWARE.ino, serial_menu.h]
2022-11-20 RNG pin/DotStar fix
2022-11-20 @mlctrez fixes
    Thanks man!
    [serial_menu.h]
2023-01-25 Added option to reverse LED order for upside-down strips
    [globals.h, led_utilities.h, serial_menu.h]
2023-01-25 Added 3.0.0 required Arduino settings image
2023-02-08 Added Modem Mode via NOISE button on boot
    [SENSORY_BRIDGE_FIRMWARE.ino, audio_transfer.h, globals.h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]
2023-10-02 Found potential cause of "stuck green LED"
    [led_utilities.h]
2024-03-21 Potential "stuck Microdose" fix
    [SENSORY_BRIDGE_FIRMWARE.ino, constants.h, globals.h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]
2024-03-21 Increase GPU thread stack size
2024-03-21 Added FreeRTOS vTaskDelay(1) to LED thread

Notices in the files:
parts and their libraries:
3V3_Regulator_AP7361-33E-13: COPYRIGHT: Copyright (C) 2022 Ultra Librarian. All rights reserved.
